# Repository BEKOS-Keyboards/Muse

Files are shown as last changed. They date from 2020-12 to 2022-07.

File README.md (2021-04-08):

# Muse
BOSS Keyboards Muse CAD and Design files

This is a full size "104" key keyboard that will run the QMK firmware, it has extra keys above the number row to allow for media control or other macros to be bound to the keys

Shield: [][cc-by-sa]

This work is licensed under a
[Creative Commons Attribution-ShareAlike 4.0 International License][cc-by-sa].

[][cc-by-sa]

[cc-by-sa]: http://creativecommons.org/licenses/by-sa/4.0/
[cc-by-sa-image]: https://licensebuttons.net/l/by-sa/4.0/88x31.png
[cc-by-sa-shield]: https://img.shields.io/badge/License-CC%20BY--SA%204.0-lightgrey.svg

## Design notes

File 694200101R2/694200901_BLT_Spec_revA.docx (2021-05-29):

Version | Changes | Date
A | Initial Release | 2021-05-25

Purpose

The purpose of this document is to describe the board level test requirements fort 694200901.

Related Documents

None

Specifications

1. The voltage at xxx shall be +5.0V +/- 0.4V
2. The voltage at xxx shall be +3.3V +/- 0.2V

694200901 Board Level Test Specification

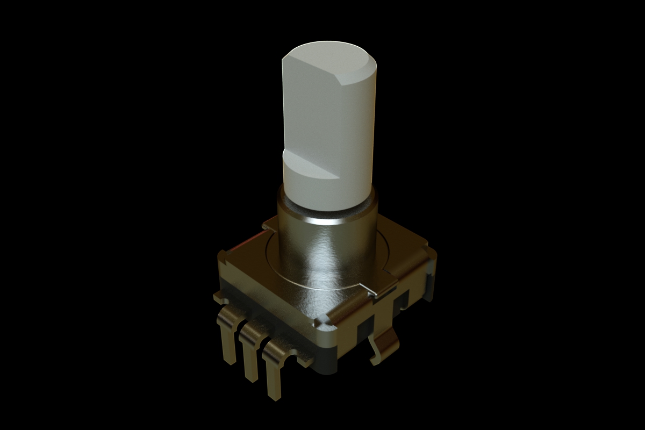
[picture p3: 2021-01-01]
3rd-party-footprints/pec11l-4xxxf-sxxxx-1.snapshot.2/Renderings/Trinityscsp__820.jpg

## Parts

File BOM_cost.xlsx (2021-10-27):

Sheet: Sheet1
part | mcmaster pn | quantity | price per | cost |  | in hand
316 Stainless Steel Pan Head Phillips Screws M2 x 0.40 mm Thread, 6mm Long | 90116A015 | 12 | 0.1023 | 1.2276 | 180 | 200
Tapered Heat-Set Inserts for Plastic Brass, M2 x 0.40 mm Thread Size, 2.900 mm Installed Length | 94180A307 | 12 | 0.1572 | 1.8864 | 180 | 200
316 Stainless Steel Pan Head Phillips Screws M3 x 0.50 mm Thread, 18mm Long | 90116A163 | 17 | 0.1151 | 1.9567 | 255 | 300
Tapered Heat-Set Inserts for Plastic Brass, M3 x 0.50 mm Thread Size, 3.800 mm Installed Length | 94180A331 | 21 | 0.1428 | 2.9988 | 315 | 400
316 Stainless Steel Pan Head Phillips Screws M3 x 0.50 mm Thread, 8mm Long | 90116A153 | 2 | 0.0695 | 0.139 | 30 | 100
316 Stainless Steel Pan Head Phillips Screws M3 x 0.50 mm Thread, 10mm Long | 90116A155 | 2 | 0.0752 | 0.1504 | 30 | 100
316 Stainless Steel Pan Head Phillips Screws M3 x 0.50 mm Thread, 14mm Long | 90116A160 | 2 | 0.1147 | 0.2294 | 30 | 100
Multipurpose Neoprene Strip with Certificate Adhesive-Back, with Certificate, 1/32" Thick, 50A Durometer, 2" x 36" | 1376N22 | 6 | 0.1048611111 | 0.6291666667 | 90 | 144
Multipurpose Neoprene Rubber Sheet 36" Wide, 1/32" Thick, 40A Durometer | 9455K91 | 1 | 3.117777778 |  | 15 | 18
Plate, Machined | xxxxx | 1 | 36.84 | 36.84 | 15 | 15
PCB |  | 1 | 29.42 | 29.42 | 15
pcb bom and assembly |  | 1 | 143.472 | 143.472 | 15
KNOB KNURLED 0.236" METAL | 226-4185-ND | 1 | 7.402666667 | 7.402666667 | 15
 |  |  |  |  |  |  | 144 | 19.2

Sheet: Sheet2
part | mcmaster pn | quantity | price per | cost |  | in hand
316 Stainless Steel Pan Head Phillips Screws M2 x 0.40 mm Thread, 6mm Long | 90116A015 | 12 | 0.1023 | 1.2276 | 180 | 200
Tapered Heat-Set Inserts for Plastic Brass, M2 x 0.40 mm Thread Size, 2.900 mm Installed Length | 94180A307 | 12 | 0.1572 | 1.8864 | 180 | 200
316 Stainless Steel Pan Head Phillips Screws M3 x 0.50 mm Thread, 18mm Long | 90116A163 | 17 | 0.1151 | 1.9567 | 255 | 300
Tapered Heat-Set Inserts for Plastic Brass, M3 x 0.50 mm Thread Size, 3.800 mm Installed Length | 94180A331 | 21 | 0.1428 | 2.9988 | 315 | 400
316 Stainless Steel Pan Head Phillips Screws M3 x 0.50 mm Thread, 8mm Long | 90116A153 | 2 | 0.0695 | 0.139 | 30 | 100
316 Stainless Steel Pan Head Phillips Screws M3 x 0.50 mm Thread, 10mm Long | 90116A155 | 2 | 0.0752 | 0.1504 | 30 | 100
316 Stainless Steel Pan Head Phillips Screws M3 x 0.50 mm Thread, 14mm Long | 90116A160 | 2 | 0.1147 | 0.2294 | 30 | 100
Multipurpose Neoprene Strip with Certificate Adhesive-Back, with Certificate, 1/32" Thick, 50A Durometer, 2" x 36" | 1376N22 | 8 | 0.1048611111 | 0.8388888889 | 120 | 144
Multipurpose Neoprene Rubber Sheet 36" Wide, 1/32" Thick, 40A Durometer | 9455K91 | 1 | 3.117777778 | 3.117777778 | 15 | 18
Plate, Machined | xxxxx | 1 | 36.84 | 36.84 | 15 | 15
PCB |  | 1 | 29.42 | 29.42 | 15
pcb bom and assembly |  | 1 | 143.472 | 143.472 | 15
duty |  | 1 | 21.3 | 21.3 | 15
KNOB KNURLED 0.236" METAL | 226-4185-ND | 1 | 7.402666667 | 7.402666667 | 15 |  |  |  |  | shipping required:
 |  | common base |  | 250.9796333 |  |  | user |  |  | Justin
extreme jet black PLA |  | 1 | 15.71285714 | 15.71285714 |  |  | Alyssa |  |  | Hume
Perect Yellow PLA |  | 1 | 14.995 | 14.995 |  |  | Hume |  |  | Griffin
Pine Green v2 PLA |  | 1 | 14.995 | 14.995 |  |  | Gerry |  |  | Megan?
Perfect Blue PLA |  | 1 | 14.995 | 14.995 |  |  | Doni |  |  | Patrick
Smoke Blue carbon Fiber |  | 1 | 26.995 | 26.995 |  |  | Doni
Perfect Orange Opaque PETG |  | 1 | 16.495 | 16.495 |  |  | Justin
Dark Blue CARBON FIBER Extreme PETG |  | 1 | 26.995 | 26.995 |  |  | Larkin
Marble v2 PETG PRO |  | 1 | 16.495 | 16.495 |  |  | Larkin
 |  |  |  |  |  |  |  | total cost ~ | 266

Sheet: Sheet3
who bought what
Doni: |  |  | John:
pcb |  |  | hardware
assembly |  |  | my filament
plate |  |  | rubber
most of the plastic |  |  | Knobs
pcb rnd1 | 2593.38
pcb rnd 2 | 441.3
plate | 552.6
duty | 319.61
total | 3906.89 | 1953.445
hardware,bags,rubber | 352.34
knobs | 111.04
packaging material
total | 463.38 | 231.69
 | larkin owes doni | 1721.755

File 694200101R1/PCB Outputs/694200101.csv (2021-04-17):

Id | Designator | Package | Quantity | Designation | Supplier and ref
1 | C27,C26,C15,C24,C22,C20,C13,C11 | CAPC1608X90N | 8 | CL10B474KA8NFNC
2 | U2 | SOT50P160X60-6N | 1 | USBLC6-2P6
3 | G1 | BossLogo | 1 | LOGO
4 | ENC1 | PEC11L4115FS0020 | 1 | PEC11L-4115F-S0020
5 | R22,R21 | RESC1508X55N | 2 | MCT06030Z0000ZP500
6 | C25 | C_0805_2012Metric | 1 | CL21A475KAQNNNE
7 | U6,U5 | QFN-48_EP_6.6x6.6_Pitch0.4mm | 2 | IS31FL3733B-QFLS4-TR
8 | D108,D107,D106,D105,D104,D103,D102,D101,D100,D99,D98,D97,D96,D95,D94,D93,D92,D91,D90,D89,D88,D87,D86,D85,D84,D83,D82,D81,D80,D79,D78,D77,D76,D75,D74,D73,D72,D71,D70,D69,D68,D67,D66,D65,D64,D63,D62,D61,D60,D59,D58,D57,D56,D55,D54,D53,D52,D51,D50,D49,D48,D47,D46,D45,D44,D43,D42,D41,D40,D39,D38,D37,D36,D35,D34,D33,D32,D31,D30,D29,D28,D27,D26,D25,D24,D23,D22,D21,D20,D19,D18,D17,D16,D15,D14,D13,D12,D11,D10,D9,D8,D7,D6,D5,D4,D3,D2,D1 | D_MiniMELF | 108 | LL4148
9 | D124,D220,D219,D218,D217,D216,D215,D214,D213,D212,D211,D210,D209,D208,D207,D206,D205,D204,D203,D202,D201,D200,D199,D198,D197,D196,D195,D194,D193,D192,D191,D190,D189,D188,D187,D186,D185,D184,D183,D182,D181,D180,D179,D178,D177,D176,D175,D174,D173,D172,D171,D170,D169,D168,D167,D166,D165,D164,D163,D162,D161,D160,D159,D158,D157,D156,D155,D154,D153,D152,D151,D150,D149,D148,D147,D146,D145,D144,D143,D142,D141,D140,D139,D138,D137,D136,D135,D134,D133,D132,D131,D130,D129,D128,D127,D126,D125,D123,D122,D121,D120,D119,D118,D117,D116,D115,D114,D113,D112,D111,D110,D109 | 4T | 112 | 19-337C_RSBHGHC-A88_4T
10 | SW77,SW95,SW85,SW82,SW92,SW9,SW44,SW43,SW42,SW41,SW40,SW107,SW106,SW105,SW104,SW103,SW102,SW101,SW100,SW99,SW98,SW97,SW96,SW94,SW93,SW91,SW90,SW89,SW88,SW87,SW86,SW84,SW83,SW81,SW80,SW79,SW78,SW76,SW75,SW74,SW73,SW72,SW71,SW70,SW69,SW68,SW67,SW66,SW65,SW64,SW63,SW62,SW61,SW60,SW59,SW58,SW57,SW56,SW55,SW54,SW53,SW52,SW51,SW50,SW49,SW48,SW47,SW46,SW45,SW39,SW38,SW37,SW36,SW35,SW34,SW33,SW32,SW31,SW30,SW29,SW28,SW27,SW26,SW25,SW24,SW23,SW22,SW21,SW20,SW19,SW18,SW17,SW16,SW15,SW14,SW13,SW12,SW11,SW10,SW8,SW7,SW6,SW5,SW4,SW3,SW2,SW1 | millmax-mxalps | 107 | MX_SW
11 | F1 | Fuse_1210_3225Metric | 1 | 1210L150THWR
12 | J2 | PinHeader_1x05_P2.54mm_Vertical | 1 | Conn_01x05_Male
13 | U3 | LQFP-64_10x10mm_P0.5mm | 1 | STM32L433RBTx
14 | SP2 | Mx_Stab_625 | 1 | MX_Stab_625
15 | H3 | MountingHole_3.5mm_Pad_TopBottom | 1 | PCB Common Earth
16 | H2,H1 | MountingHole_M2_edge | 2 | Mounting Slot
17 | FB1 | Yageo-RC0603-0-0-IPC_C | 1 | BBUP00160808600Y00
18 | CR1 | SMAJ9.0CA | 1 | SMAJ9.0CA
19 | C6,C3 | AVX-GRM124-0-0-IPC_C | 2 | 06035A100JAT2A
20 | C2 | Samsung-CL10-0-0-IPC_C | 1 | CL10B105KA8NNNC
21 | C10,C9,C5 | Samsung-0603_1608_Metric-0-0-0 | 3 | CL10B103KB8NNNC
22 | C1,C23,C21,C12,C19,C16,C14,C8,C7,C4 | Samsung-CL10-09_2006-0-IPC_C | 10 | CL10B104KB8NNNL
23 | R8,R7,R6,R5,R4,R3 | RESC2012X65N | 6 | RMCF0805FT510R
24 | SP8,SP7,SP6,SP3 | Mx_Stab_200 | 4 | MX_Stab_200
25 | SP5 | Mx_Stab_275 | 1 | MX_Stab_275
26 | SP4,SP1 | Mx_Stab_225 | 2 | MX_Stab_225
27 | Y1 | XTAL_ECS-480-10-33B-CKM-TR | 1 | ECS-480-10-33B-CKM-TR
28 | C18,C17 | CAPPC3528X210N | 2 | TAJB226K016RNJ
29 | R2,R1 | Yageo-RC0603-0-0-IPC_C | 2 | RC0603FR-075K1L
30 | R20,R17 | RESC6332X70N | 2 | RMCF2512FT20K0
31 | R19,R18,R16,R15 | RESC1508X55N | 4 | RMCF0603FT100K
32 | R10,R9 | RESC1508X55N | 2 | RMCF0603FT1K00
33 | R14,R13,R12,R11 | RESC1508X50N | 4 | RNCP0603FTD10K0
34 | U1 | AP2114HA-3.3TRG1 | 1 | AP2114HA-3.3TRG1
35 | J1 | Global_Connector_Technology-USB4085-GF-A-MFG | 1 | USB4085-GF-A
36 | U4 | STMicroelectronics-SO8N-SO-A-0-2-IPC_C | 1 | M24M02-DRMN6TP
37 | J3 | PinHeader_1x02_P2.54mm_Vertical | 1 | Conn_01x02_Male

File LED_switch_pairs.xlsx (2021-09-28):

U5
D109 | D113 | D117 | D121 | D125 | D129 | D133 | D137 | D141 | D145 | D149 | D153 | D157 | D161 | D165 | D169
1 | 9 | 14 | 20 | 25 | 35 | 40 | 45 | 50 | 56 | 62 | 66 | 71 | 75 | 79 | 84
D110 | D114 | D118 | D122 | D126 | D130 | D134 | D138 | D142 | D146 | D150 | D154 | D158 | D162 | D166 | D170
2 | 6 | 10 | 15 | 21 | 26 | 30 | 36 | 41 | 46 | 51 | 57 | 63 | 72 | 76 | 80
D111 | D115 | D119 | D123 | D127 | D131 | D135 | D139 | D143 | D147 | D151 | D155 | D159 | D163 | D167 | D171
3 | 11 | 16 | 22 | 27 | 31 | 37 | 42 | 47 | 52 | 58 | 64 | 67 | 73 | 77 | 81 | 64
D112 | D116 | D120 | D124 | D128 | D132 | D136 | D140 | D144 | D148 | D152 | D156 | D160 | D164 | D168 | D172
4 | 7 | 12 | 17 | 23 | 28 | 32 | 38 | 43 | 48 | 53 | 59 | 65 | 68 | 86 | 85
U6
D173 | D177 | D181 | D185 | D189 | D193 | D197 | D201 | D205 | D209 | D213 | D217
13 | 18 | 24 | 33 | 39 | 44 | 49 | 54 | 60 | 69 | 82 | ind1 |  |  |  |  | 48
D174 | D178 | D182 | D186 | D190 | D194 | D198 | D202 | D206 | D210 | D214 | D218 |  |  |  |  | 112
5 | 8 | 19 | 29 | 34 | 55 | 61 | 70 | 74 | 78 | 83 | 87
D175 | D179 | D183 | D187 | D191 | D195 | D199 | D203 | D207 | D211 | D215 | D219
91 | 97 | 102 | 100 | 96 | 101 | 90 | 95 | 89 | 88 | 94 | 99
D176 | D180 | D184 | D188 | D192 | D196 | D200 | D204 | D208 | D212 | D216 | D220
92 | 98 | 103 | 104 | 107 | 106 | 93 | 105 | ind5 | ind4 | ind3 | ind2

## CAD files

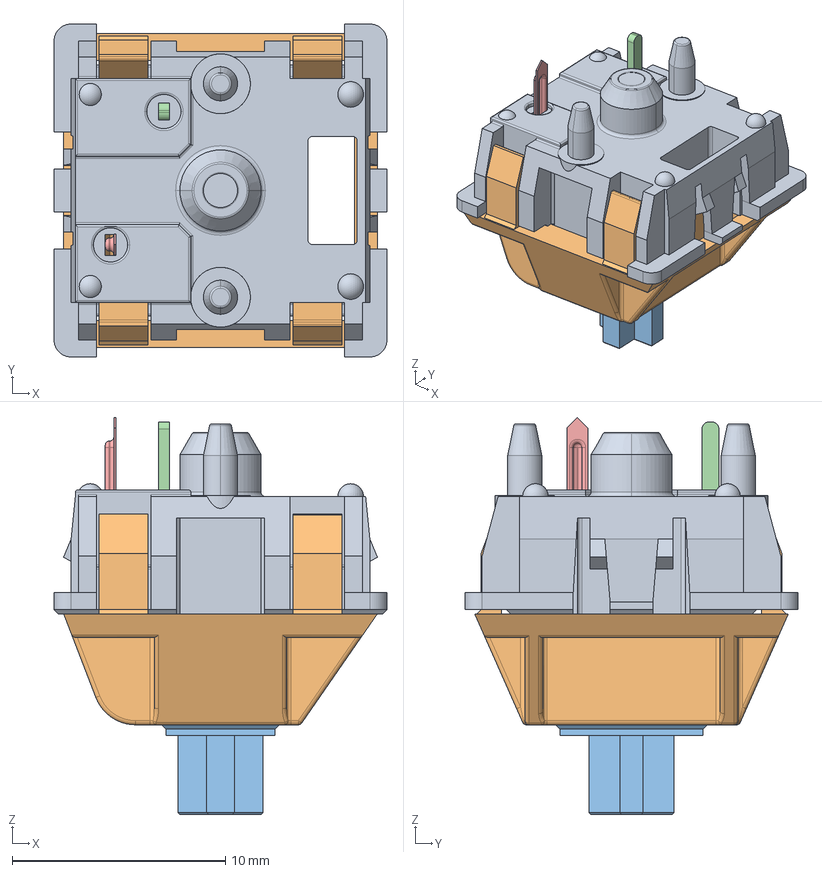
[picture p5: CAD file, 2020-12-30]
3rd-party-footprints/cherry-mx-1.snapshot.3/asm_mx_asm_PCB.stp
15.6 x 15.6 x 18.6 mm
MX_DOWN
MX_UP
UP_MX
MX_PIN
MX_SPRING
MX_CLICK

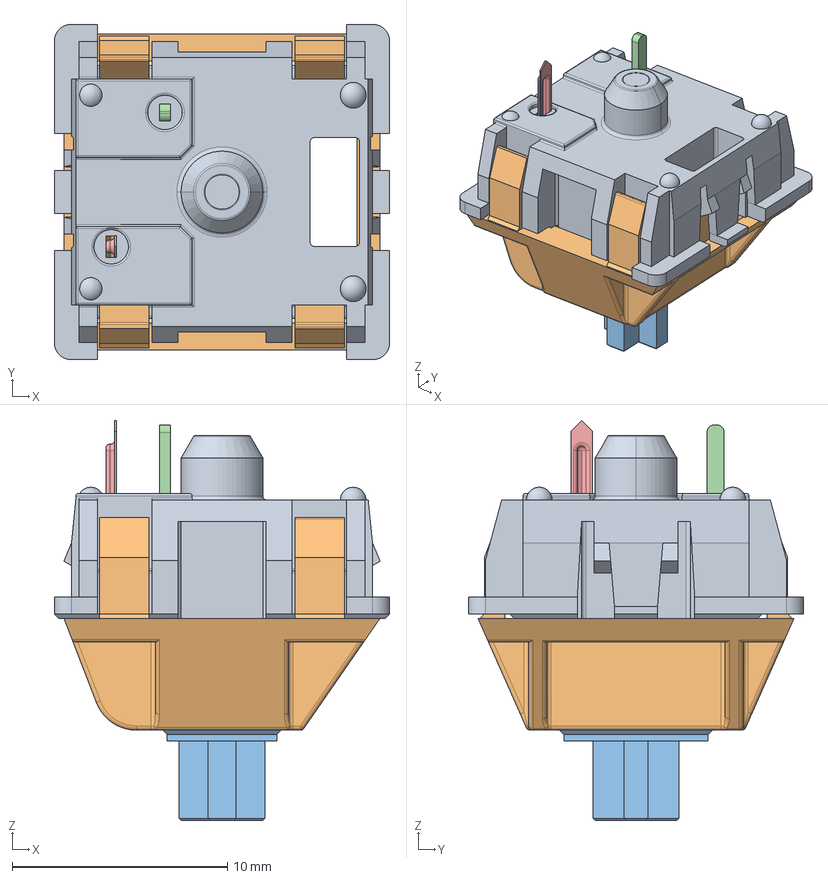
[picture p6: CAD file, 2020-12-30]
3rd-party-footprints/cherry-mx-1.snapshot.3/asm_mx_asm_PLATE.stp
15.6 x 15.6 x 18.6 mm
MX_DOWN
MX_UP
UP_MX
MX_PIN
MX_SPRING
MX_CLICK

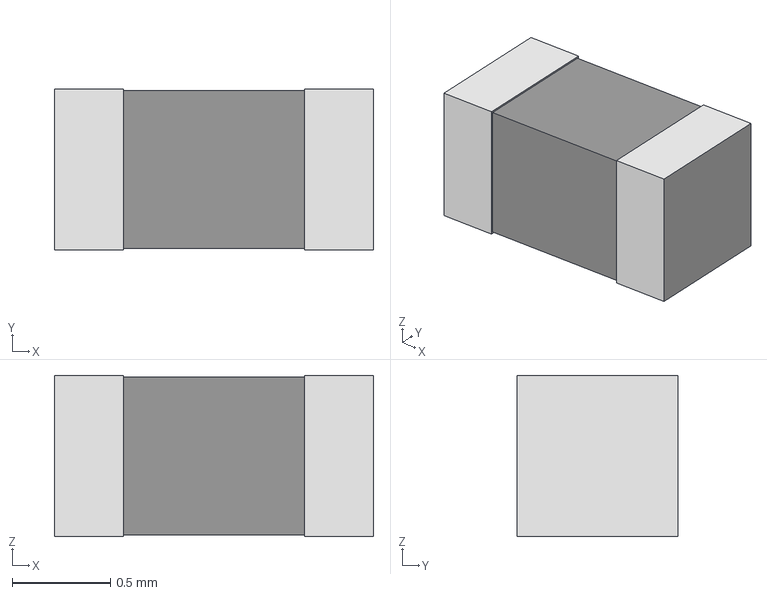
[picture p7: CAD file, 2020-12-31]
3rd-party-footprints/Cap_AVX_06035A100JAT2A/eec.models/AVX_-_06035A100JAT2A.step
1.62 x 0.82 x 0.82 mm

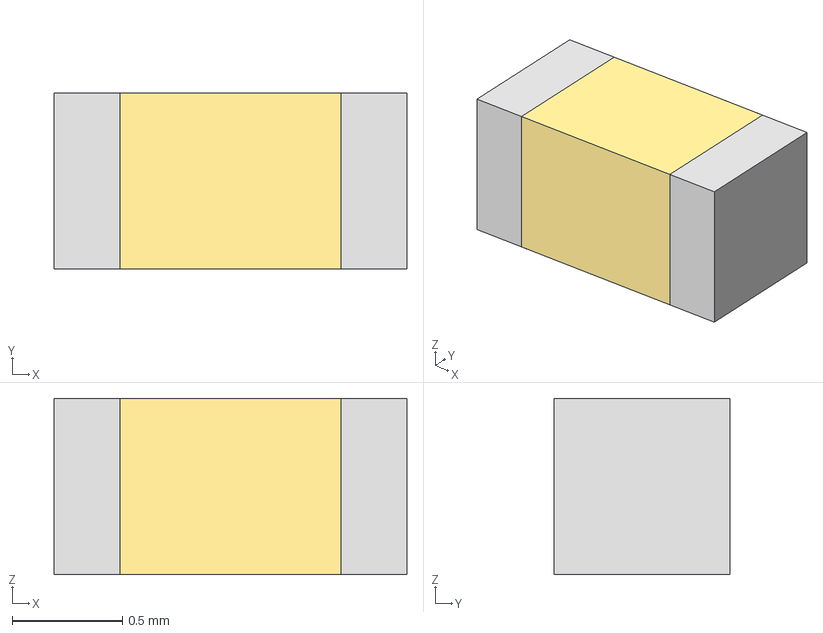
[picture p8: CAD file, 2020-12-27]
3rd-party-footprints/Cap_Samsung_CL10B103KB8NNNC/eec.models/Samsung_-_CL10B103KB8NNNC.step
1.60 x 0.8 x 0.8 mm

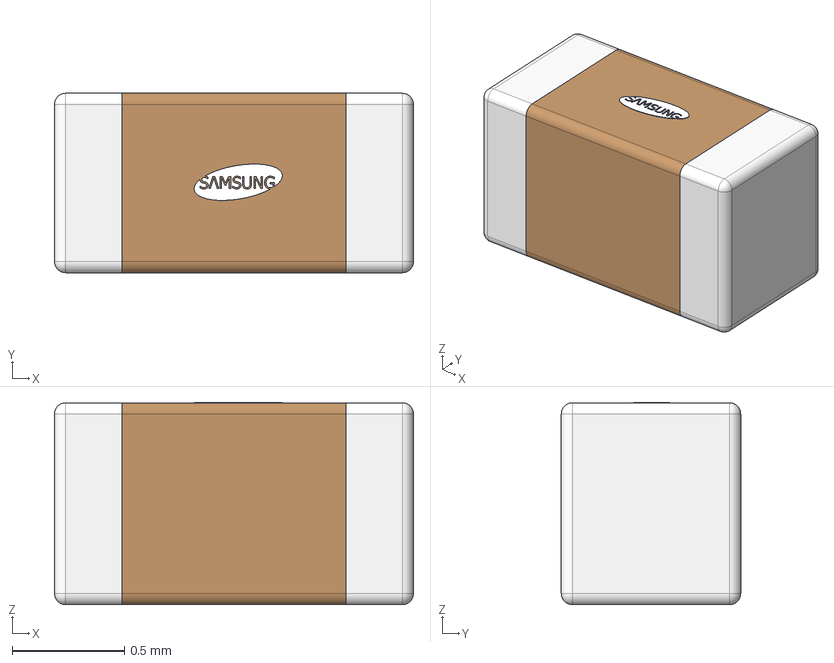
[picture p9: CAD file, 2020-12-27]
3rd-party-footprints/Cap_Samsung_CL10B104KB8NNNL/eec.models/Samsung_-_CL10B104KB8NNNL.step
1.60 x 0.8 x 0.902 mm
Samsung logo

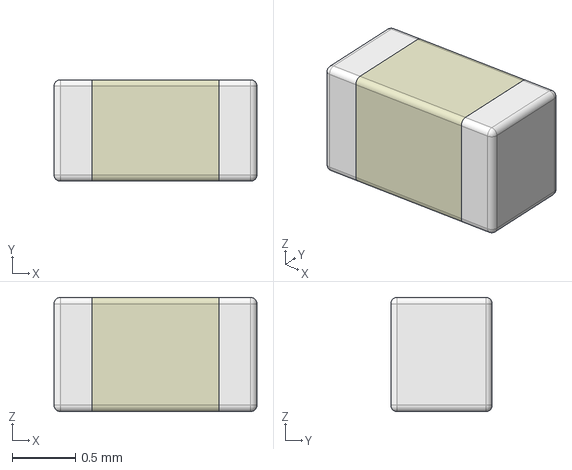
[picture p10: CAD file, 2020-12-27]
3rd-party-footprints/Cap_Samsung_CL10B105KA8NNNC/eec.models/Samsung_-_CL10B105KA8NNNC.step
1.60 x 0.8 x 0.9 mm

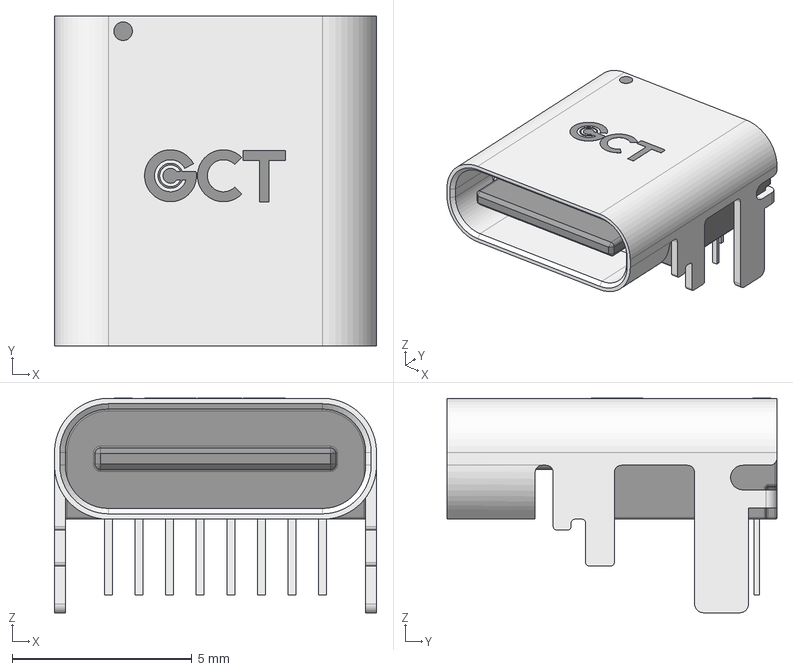
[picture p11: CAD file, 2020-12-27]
3rd-party-footprints/Conn_Global Connector Technology_USB4085-GF-A/eec.models/Global_Connector_Technology_-_USB4085-GF-A.step
8.95 x 9.17 x 5.96 mm
housing
plastic
pins
logo

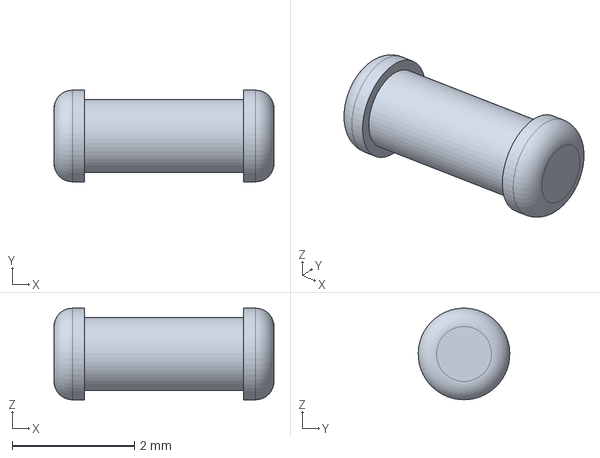
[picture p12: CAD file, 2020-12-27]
3rd-party-footprints/Diode_Fairchild_ON Semiconductor_LL4148/eec.models/Fairchild/ON_Semiconductor_-_LL4148.step
3.60 x 1.50 x 1.50 mm

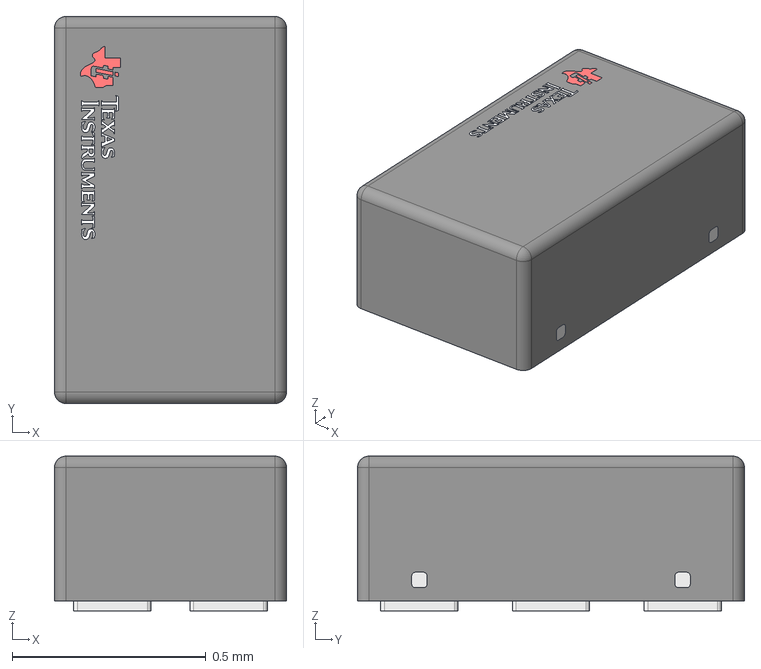
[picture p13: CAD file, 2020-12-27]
3rd-party-footprints/Diode_Texas Instruments_ESD122DMXR/eec.models/Texas_Instruments_-_ESD122DMXR.step
0.6 x 1.00 x 0.4 mm

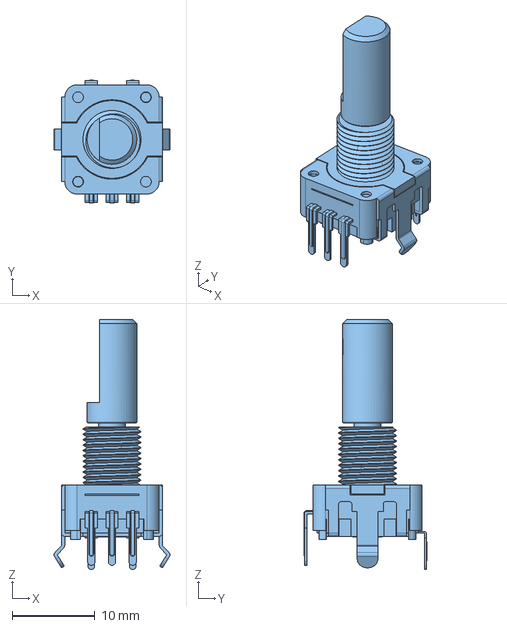
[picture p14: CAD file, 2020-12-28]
3rd-party-footprints/Enc_Bourns_PEC11R-4220F-S0024/eec.models/Bourns_-_PEC11R-4220F-S0024.step
14.0 x 14.9 x 30.2 mm

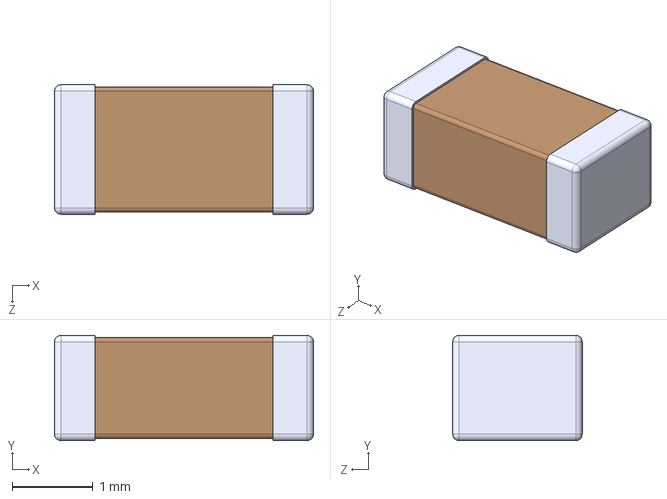
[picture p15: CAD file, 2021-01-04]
3rd-party-footprints/FBMJ3216HM600-T/FBMJ3216HM600-T.step
3.20 x 1.30 x 1.60 mm

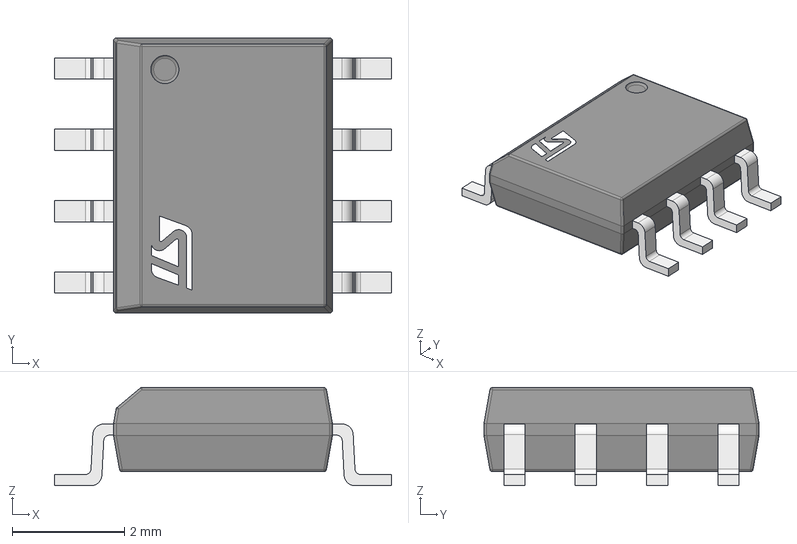
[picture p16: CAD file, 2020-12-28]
3rd-party-footprints/IC_STMicroelectronics_M24M02-DRMN6TP/eec.models/STMicroelectronics_-_M24M02-DRMN6TP.step
6.00 x 4.90 x 1.75 mm
pins
logo1

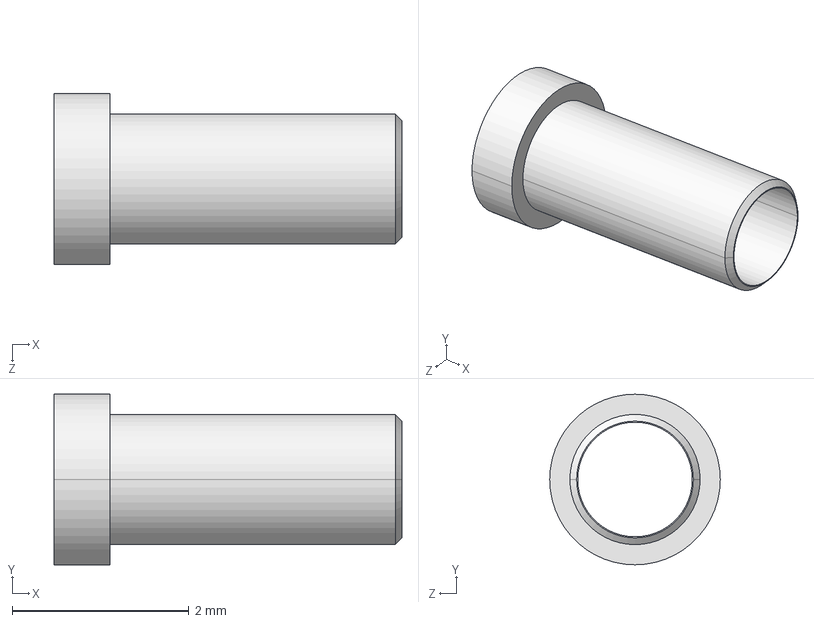
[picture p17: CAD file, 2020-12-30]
3rd-party-footprints/MillMax/mill-max-0305-2-15-80-47-XX-10-0.step
3.94 x 1.93 x 1.93 mm

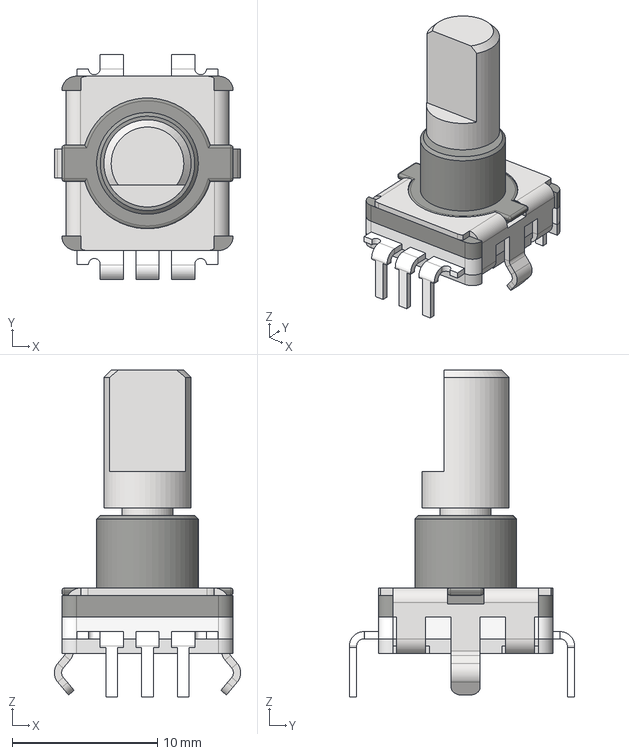
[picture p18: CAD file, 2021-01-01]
3rd-party-footprints/pec11l-4xxxf-sxxxx-1.snapshot.2/PEC11L-4xxxF-Sxxxx.stp
12.8 x 15.5 x 22.5 mm

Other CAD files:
3rd-party-footprints/CL10B474KA8NFNC/CL10B474KA8NFNC.step
3rd-party-footprints/RMCF0603FT100K/RMCF0603FT100K.step
3rd-party-footprints/RMCF0603FT1K00/RMCF0603FT1K00.step
3rd-party-footprints/RMCF0805FT510R/RMCF0805FT510R.step
3rd-party-footprints/19-337C_RSBHGHC-A88_4T.step
3rd-party-footprints/JS102011SAQN.STEP
3rd-party-footprints/RMCF2512FT20K0/RMCF2512FT20K0.step
3rd-party-footprints/RNCP0603FTD10K0/RNCP0603FTD10K0.step
3rd-party-footprints/TAJB226K016RNJ/TAJB226K016RNJ.step
3rd-party-footprints/USBLC6-2P6/USBLC6-2P6.step
3rd-party-footprints/smd-quartz-3-2x2-5mm-1.snapshot.5/KX7 SMD Quartz Crystal Resonator 3.2x2.5mm.step
3rd-party-footprints/ul_SMAJ90CA/KiCAD/2021-01-04_17-23-41/STEP/SMASeries_LTF.step
keyboard-layout/kb-plate-modded.dxf
keyboard-layout/kb-plate.dxf

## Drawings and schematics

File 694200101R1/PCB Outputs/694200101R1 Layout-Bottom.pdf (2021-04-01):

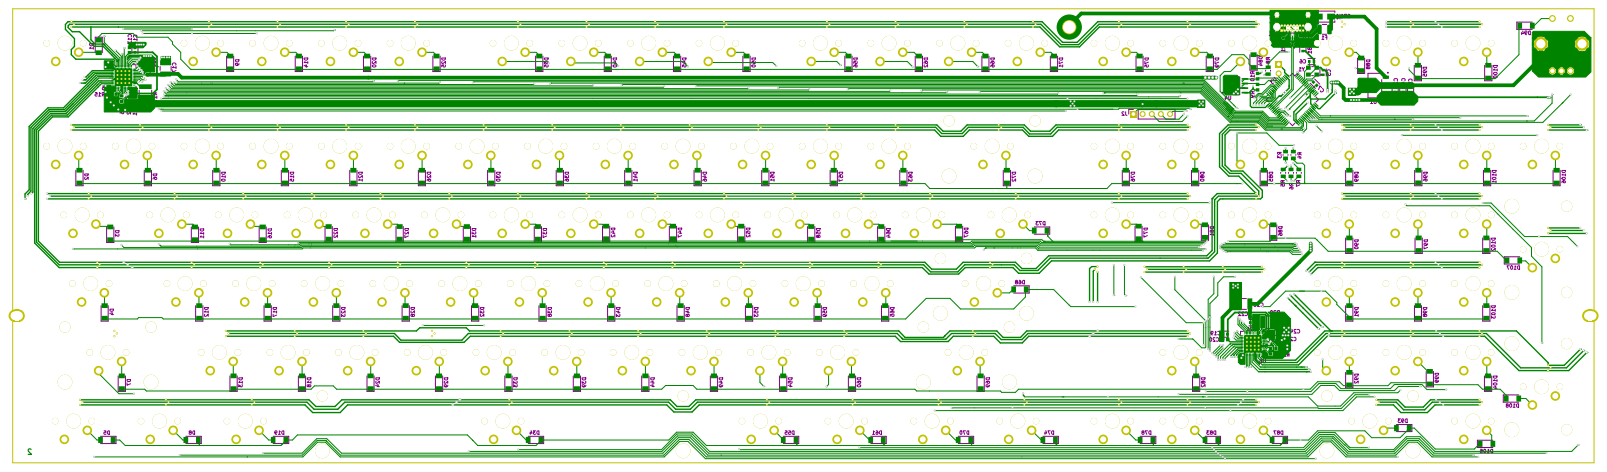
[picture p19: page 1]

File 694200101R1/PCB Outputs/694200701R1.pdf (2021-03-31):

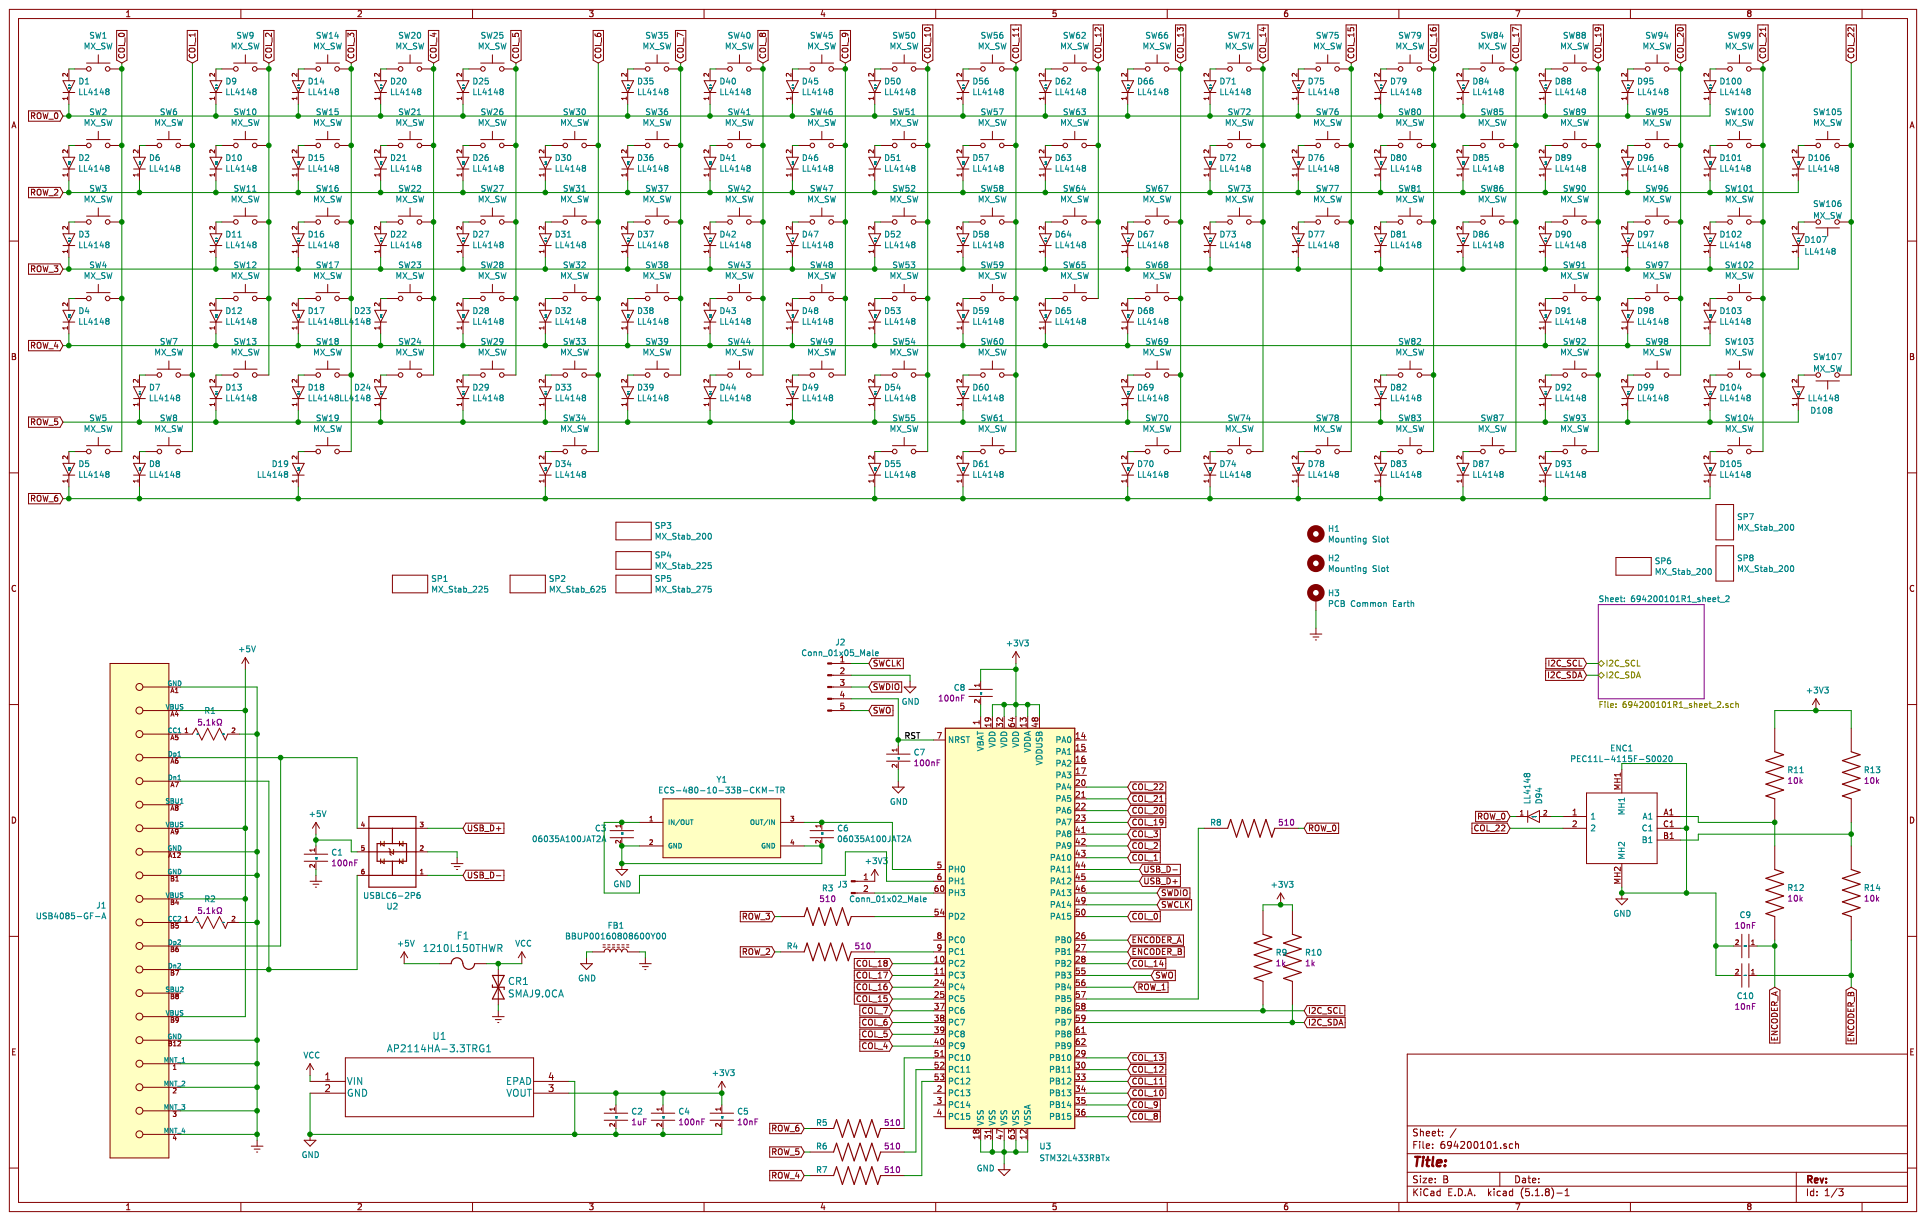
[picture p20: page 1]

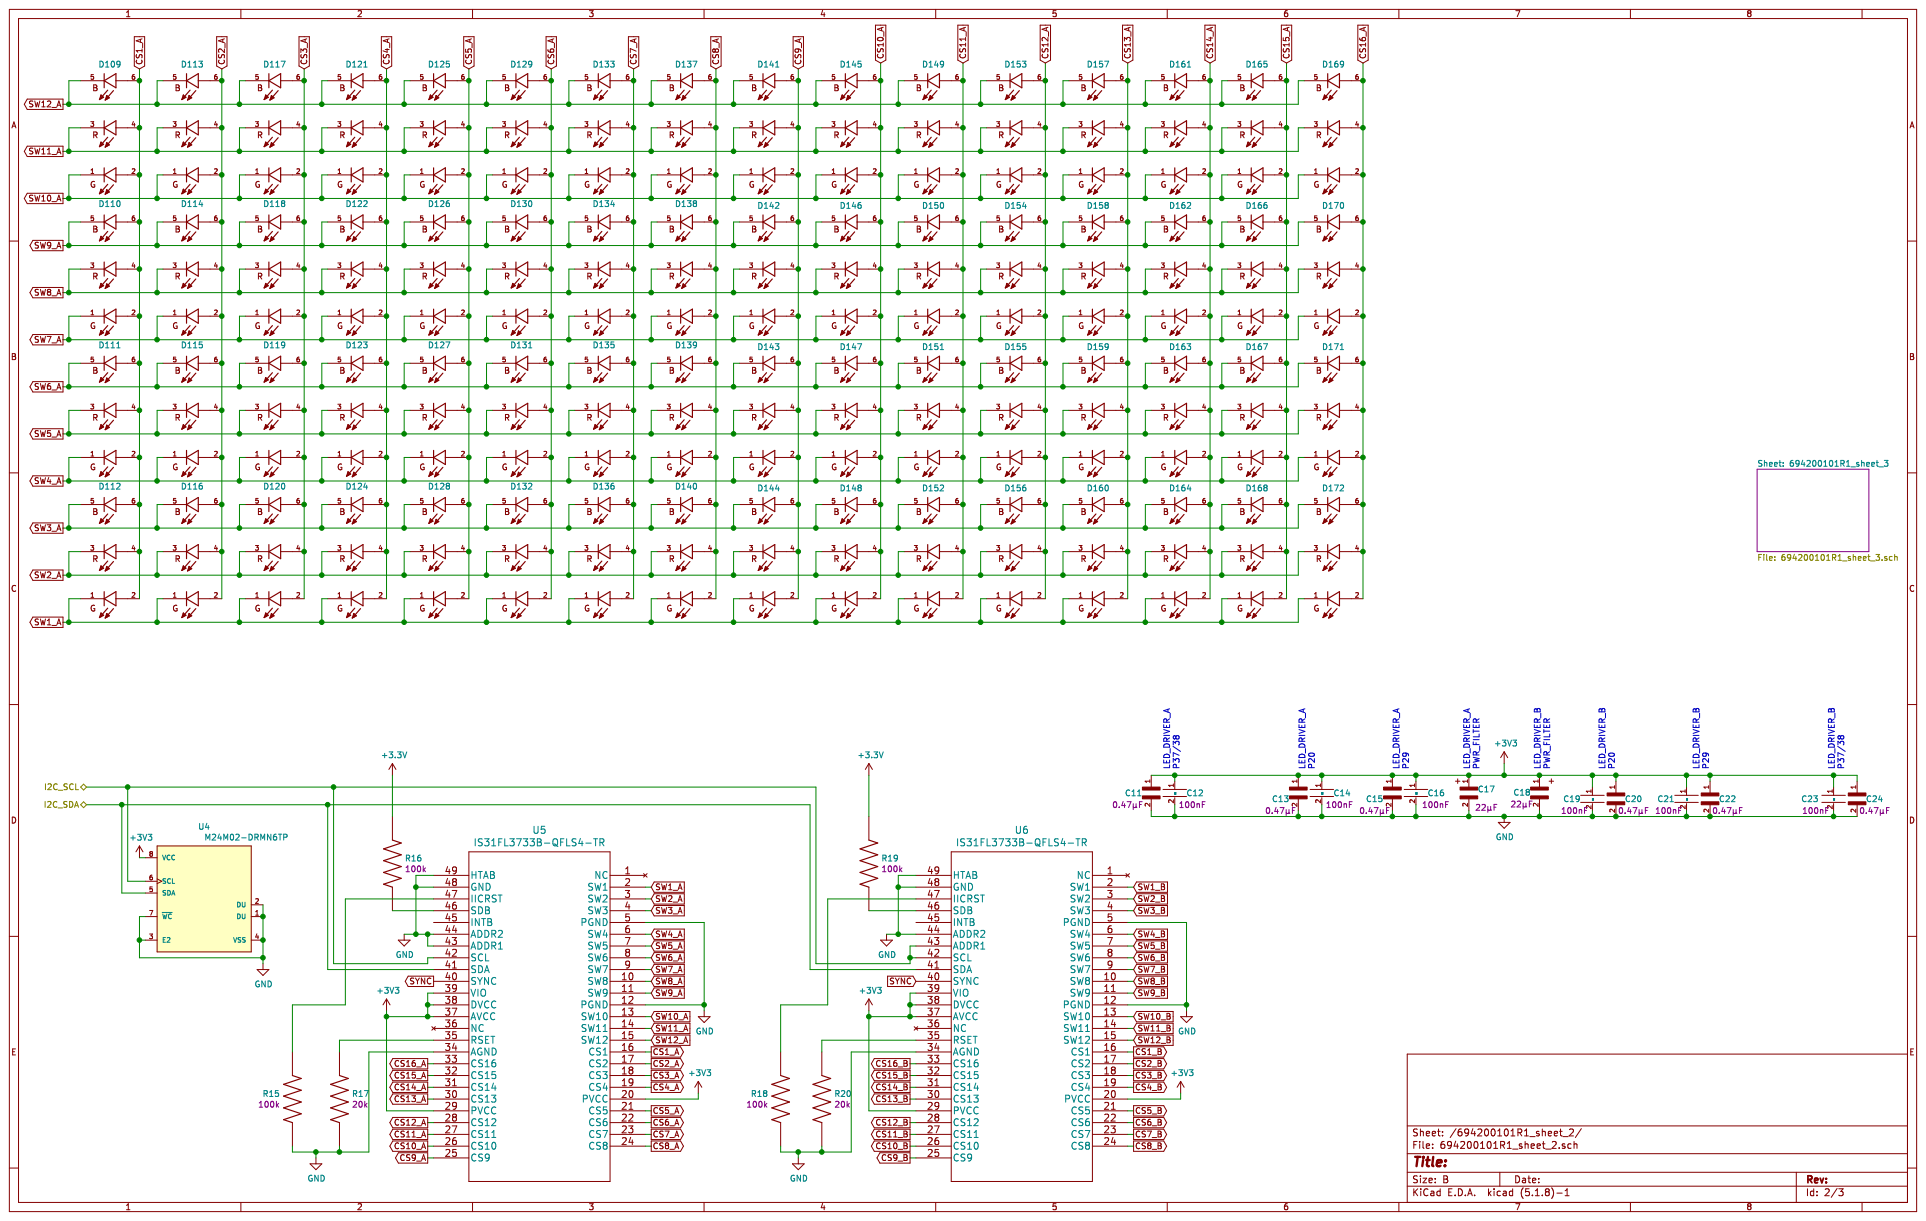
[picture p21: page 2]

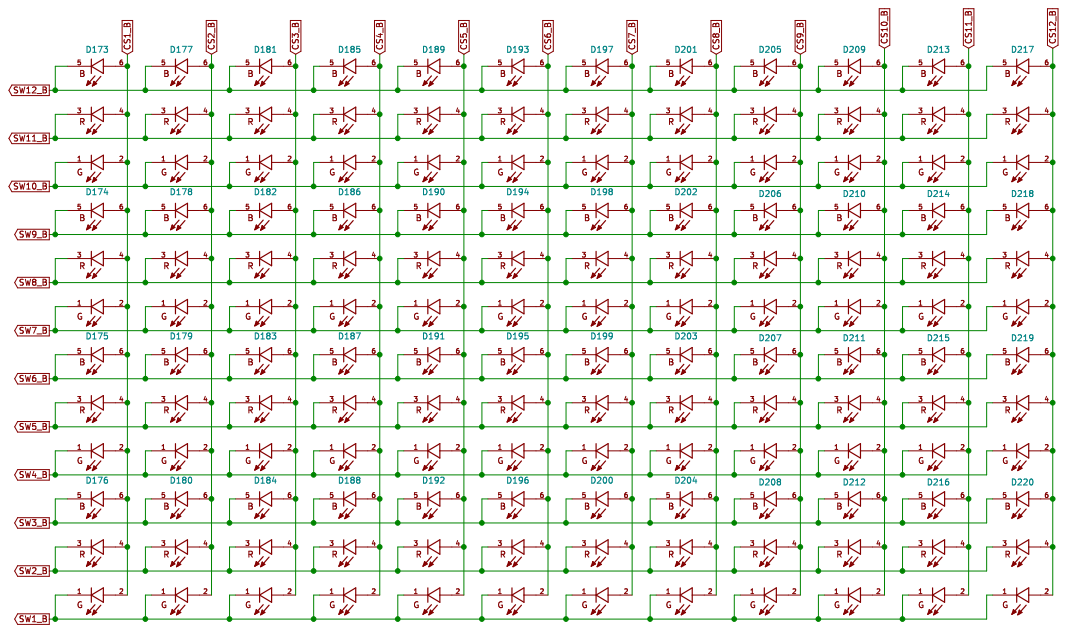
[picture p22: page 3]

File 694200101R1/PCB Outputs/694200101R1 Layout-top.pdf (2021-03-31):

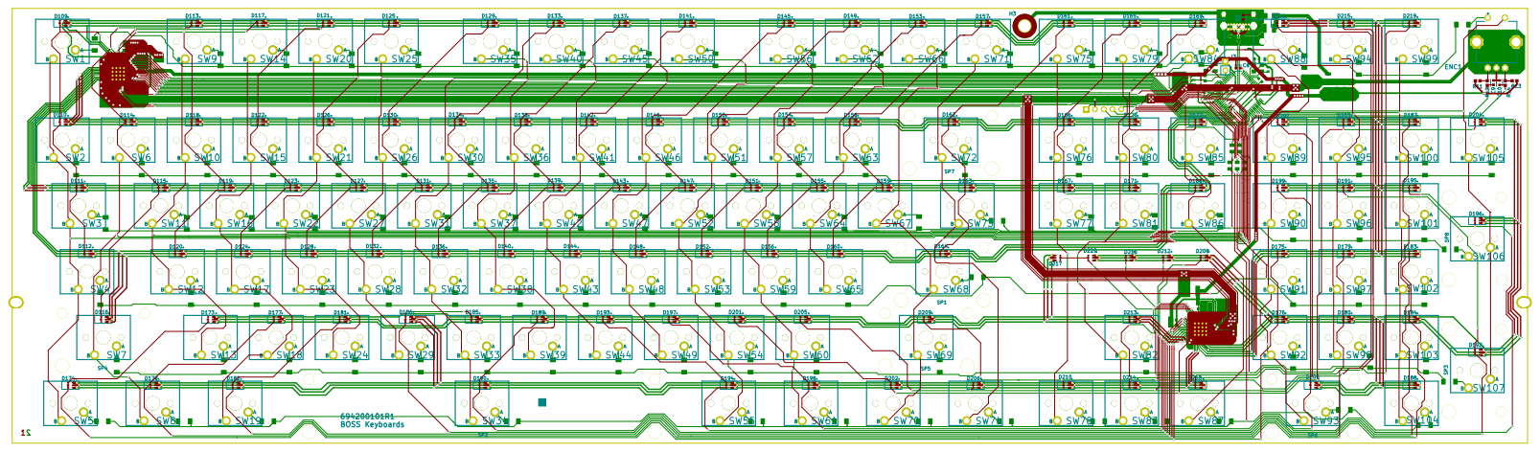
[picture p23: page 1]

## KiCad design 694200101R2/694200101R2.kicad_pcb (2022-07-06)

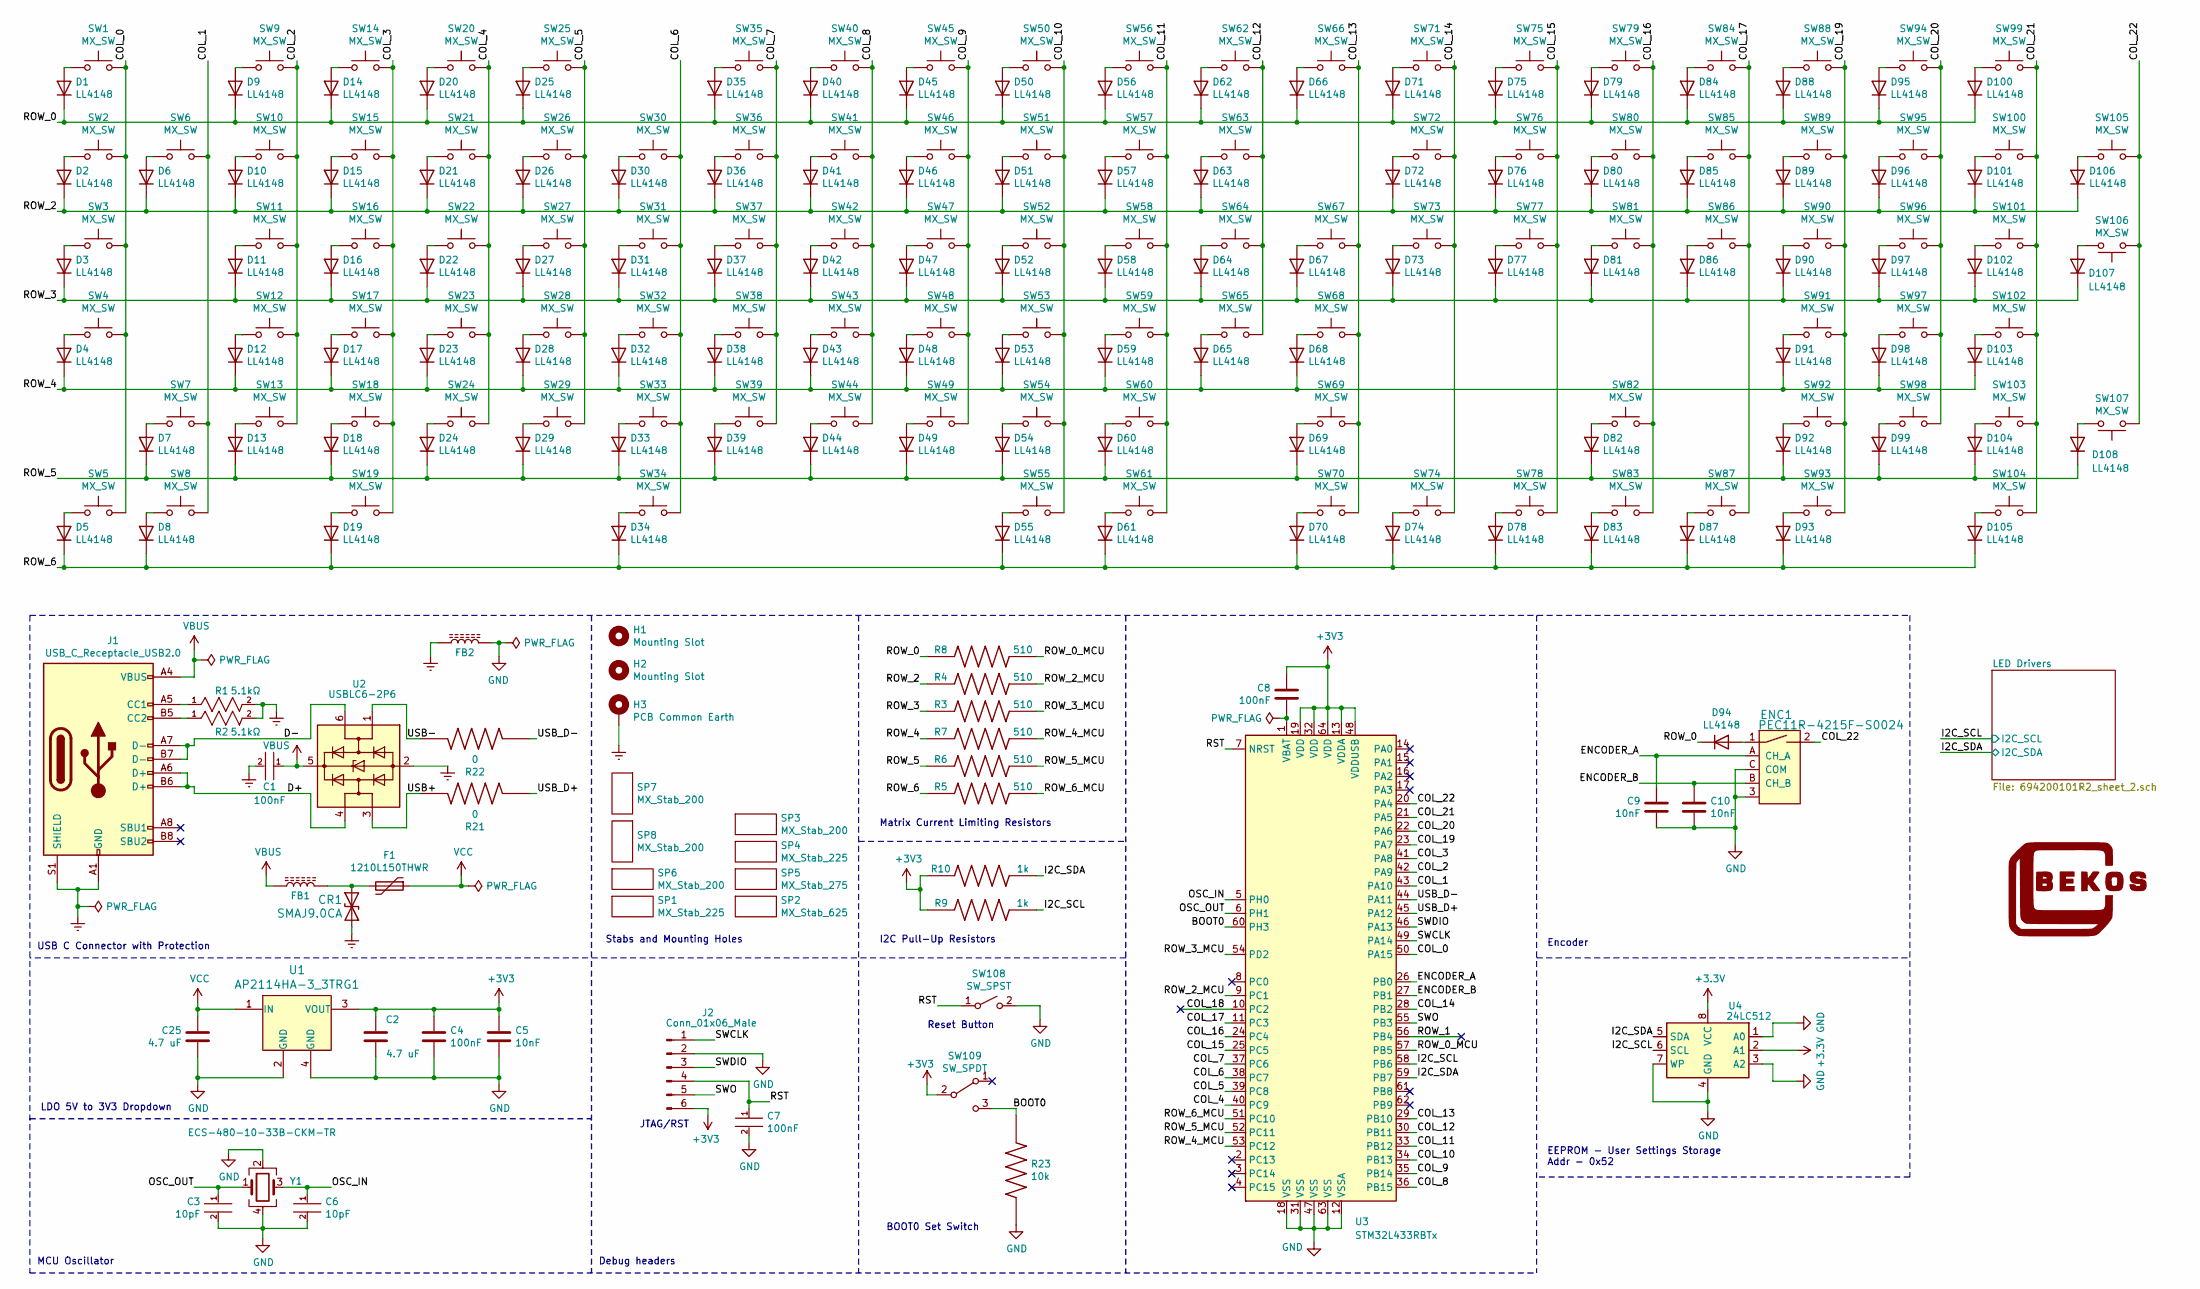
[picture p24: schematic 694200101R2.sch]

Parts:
C1, C7: CL10B104KB8NNNL; C_0603_1608Metric; tolerance 10%; voltage rating 50V
C2, C25: 4.7 uF; C_0805_2012Metric
C3, C6: 06035A100JAT2A; C_0603_1608Metric; tolerance 5%; voltage rating 50V; mouser part number 581-06035A100J; digikey description CAP CER 10PF 50V C0G/NP0 0603
C4, C8: 100nF; C_0603_1608Metric
C5, C9, C10: 10nF; C_0603_1608Metric
CR1: SMAJ9.0CA
D1, D9, D14, D20, D25, D35, D40, D45, D50, D56, D62, D66, D71, D75, D79: LL4148; D_MiniMELF
D2, D3, D4, D5, D6, D7, D8, D10, D11, D12, D13, D15, D16, D17, D18, D19, D21, D22, D23, D24, D26, D27, D28, D29, D30, D31, D32, D33, D34, D36, D37, D38, D39, D41, D42, D43, D44, D46, D47, D48, D49, D51, D52, D53, D54, D55, D57, D58, D59, D60, D61, D63, D64, D65, D67, D68, D69, D70, D72, D73, D74, D76, D77, D78, D80, D81, D82, D83, D84, D85, D86, D87, D88, D89, D90, D91, D92, D93, D94, D95, D96, D97, D98, D99, D100, D101, D102, D103, D104, D105, D106, D107, D108: LL4148; D_MiniMELF; mouser part number 512-LL4148; digikey description DIODE GEN PURP 100V 200MA SOD80
ENC1: PEC11R-4215F-S0024; Rotary_Encoder_Switched_PEC11R; MPN PEC11R-4215F-S0024; Digi-Key_PN PEC11R-4215F-S0024-ND
F1: 1210L150THWR; Fuse_1210_3225Metric_Castellated
FB1, FB2: FBMJ3216HM600-T; L_1206_3216Metric
H1, H2: Mounting Slot; MountingHole_M2_edge
H3: PCB Common Earth; MountingHole_3.5mm_Pad_TopBottom
J1: USB_C_Receptacle_USB2.0; USB_C_Receptacle_GCT_USB4085
J2: Conn_01x06_Male; PinHeader_1x06_P2.54mm_Vertical
R1, R2: RC0603FR-075K1L; R_0603_1608Metric; power rating 0.1W; tolerance 1%; mouser part number 603-RC0603FR-075K1L; digikey description RES SMD 5.1K OHM 1% 1/10W 0603
R3, R4, R5, R6, R7, R8: RMCF0805FT510R; R_0805_2012Metric
R9, R10: RMCF0603FT1K00; R_0603_1608Metric
R21, R22: MCT06030Z0000ZP500; R_0603_1608Metric
R23: RNCP0603FTD10K0; R_0603_1608Metric
SP1, SP4: MX_Stab_225; Mx_Stab_225
SP2: MX_Stab_625; Mx_Stab_625
SP3, SP6, SP7, SP8: MX_Stab_200; Mx_Stab_200
SP5: MX_Stab_275; Mx_Stab_275
SW1, SW2, SW3, SW4, SW5, SW6, SW7, SW8, SW9, SW10, SW11, SW12, SW13, SW14, SW15, SW16, SW17, SW18, SW19, SW20, SW21, SW22, SW23, SW24, SW25, SW26, SW27, SW28, SW29, SW30, SW31, SW32, SW33, SW34, SW35, SW36, SW37, SW38, SW39, SW40, SW41, SW42, SW43, SW44, SW45, SW46, SW47, SW48, SW49, SW50, SW51, SW52, SW53, SW54, SW55, SW56, SW57, SW58, SW59, SW60, SW61, SW62, SW63, SW64, SW65, SW66, SW67, SW68, SW69, SW70, SW71, SW72, SW73, SW74, SW75, SW76, SW77, SW78, SW79, SW80, SW81, SW82, SW83, SW84, SW85, SW86, SW87, SW88, SW89, SW90, SW91, SW92, SW93, SW94, SW95, SW96, SW97, SW98, SW99, SW100, SW101, SW102, SW103, SW104, SW105, SW106, SW107: MX_SW; millmax-mxalps
SW108: SW_SPST; SW_SPST_TL3342
SW109: SW_SPDT; SW_SPDT_PCM12
U1: AP2114HA-3_3TRG1; SOT-223; MPN AP2114H-3.3TRG1; Digi-Key_PN AP2114H-3.3TRG1DICT-ND
U2: USBLC6-2P6; SOT-666
U3: STM32L433RBTx; LQFP-64_10x10mm_P0.5mm
U4: 24LC512; SOIC-8_3.9x4.9mm_P1.27mm
Y1: ECS-480-10-33B-CKM-TR; XTAL_ECS-480-10-33B-CKM-TR

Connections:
/BOOT0: R23.1, SW109.3 (C), U3.60 (PH3)
/COL_0: SW1.2, SW2.2, SW3.2, SW4.2, SW5.2, U3.50 (PA15)
/COL_1: SW6.2, SW7.2, SW8.2, U3.43 (PA10)
/COL_2: SW9.2, SW10.2, SW11.2, SW12.2, SW13.2, U3.42 (PA9)
/COL_3: SW14.2, SW15.2, SW16.2, SW17.2, SW18.2, SW19.2, U3.41 (PA8)
/COL_4: SW20.2, SW21.2, SW22.2, SW23.2, SW24.2, U3.40 (PC9)
/COL_5: SW25.2, SW26.2, SW27.2, SW28.2, SW29.2, U3.39 (PC8)
/COL_6: SW30.2, SW31.2, SW32.2, SW33.2, SW34.2, U3.38 (PC7)
/COL_7: SW35.2, SW36.2, SW37.2, SW38.2, SW39.2, U3.37 (PC6)
/COL_8: SW40.2, SW41.2, SW42.2, SW43.2, SW44.2, U3.36 (PB15)
/COL_9: SW45.2, SW46.2, SW47.2, SW48.2, SW49.2, U3.35 (PB14)
/COL_10: SW50.2, SW51.2, SW52.2, SW53.2, SW54.2, SW55.2, U3.34 (PB13)
/COL_11: SW56.2, SW57.2, SW58.2, SW59.2, SW60.2, SW61.2, U3.33 (PB12)
/COL_12: SW62.2, SW63.2, SW64.2, SW65.2, U3.30 (PB11)
/COL_13: SW66.2, SW67.2, SW68.2, SW69.2, SW70.2, U3.29 (PB10)
/COL_14: SW71.2, SW72.2, SW73.2, SW74.2, U3.28 (PB2)
/COL_15: SW75.2, SW76.2, SW77.2, SW78.2, U3.25 (PC5)
/COL_16: SW79.2, SW80.2, SW81.2, SW82.2, SW83.2, U3.24 (PC4)
/COL_17: SW84.2, SW85.2, SW86.2, SW87.2, U3.11 (PC3)
/COL_18: U3.10 (PC2)
/COL_19: SW88.2, SW89.2, SW90.2, SW91.2, SW92.2, SW93.2, U3.23 (PA7)
/COL_20: SW94.2, SW95.2, SW96.2, SW97.2, SW98.2, U3.22 (PA6)
/COL_21: SW99.2, SW100.2, SW101.2, SW102.2, SW103.2, SW104.2, U3.21 (PA5)
/COL_22: ENC1.2, SW105.2, SW106.1, SW107.1, U3.20 (PA4)
/D+: J1.A6 (D+), J1.B6 (D+), U2.4 (I/O2)
/D-: J1.A7 (D-), J1.B7 (D-), U2.6 (I/O1)
/ENCODER_A: C9.1, ENC1.A (CH_A), U3.26 (PB0)
/ENCODER_B: C10.1, ENC1.B (CH_B), U3.27 (PB1)
/I2C_SCL: R9.2, U3.58 (PB6), U4.6 (SCL); also elsewhere on the board
/I2C_SDA: R10.2, U3.59 (PB7), U4.5 (SDA); also elsewhere on the board
/OSC_IN: C6.1, U3.5 (PH0), Y1.3
/OSC_OUT: C3.1, U3.6 (PH1), Y1.1
/ROW_0: D1.1 (K), D9.1 (K), D14.1 (K), D20.1 (K), D25.1 (K), D35.1 (K), D40.1 (K), D45.1 (K), D50.1 (K), D56.1 (K), D62.1 (K), D66.1 (K), D71.1 (K), D75.1 (K), D79.1 (K), D84.1 (K), D88.1 (K), D94.1 (K), D95.1 (K), D100.1 (K), R8.2
/ROW_0_MCU: R8.1, U3.57 (PB5)
/ROW_1: U3.56 (PB4)
/ROW_2: D2.1 (K), D6.1 (K), D10.1 (K), D15.1 (K), D21.1 (K), D26.1 (K), D30.1 (K), D36.1 (K), D41.1 (K), D46.1 (K), D51.1 (K), D57.1 (K), D63.1 (K), D72.1 (K), D76.1 (K), D80.1 (K), D85.1 (K), D89.1 (K), D96.1 (K), D101.1 (K), D106.1 (K), R4.1
/ROW_2_MCU: R4.2, U3.9 (PC1)
/ROW_3: D3.1 (K), D11.1 (K), D16.1 (K), D22.1 (K), D27.1 (K), D31.1 (K), D37.1 (K), D42.1 (K), D47.1 (K), D52.1 (K), D58.1 (K), D64.1 (K), D67.1 (K), D73.1 (K), D77.1 (K), D81.1 (K), D86.1 (K), D90.1 (K), D97.1 (K), D102.1 (K), D107.1 (K), R3.1
/ROW_3_MCU: R3.2, U3.54 (PD2)
/ROW_4: D4.1 (K), D12.1 (K), D17.1 (K), D23.1 (K), D28.1 (K), D32.1 (K), D38.1 (K), D43.1 (K), D48.1 (K), D53.1 (K), D59.1 (K), D65.1 (K), D68.1 (K), D91.1 (K), D98.1 (K), D103.1 (K), R7.1
/ROW_4_MCU: R7.2, U3.53 (PC12)
/ROW_5: D7.1 (K), D13.1 (K), D18.1 (K), D24.1 (K), D29.1 (K), D33.1 (K), D39.1 (K), D44.1 (K), D49.1 (K), D54.1 (K), D60.1 (K), D69.1 (K), D82.1 (K), D92.1 (K), D99.1 (K), D104.1 (K), D108.1 (K), R6.1
/ROW_5_MCU: R6.2, U3.52 (PC11)
/ROW_6: D5.1 (K), D8.1 (K), D19.1 (K), D34.1 (K), D55.1 (K), D61.1 (K), D70.1 (K), D74.1 (K), D78.1 (K), D83.1 (K), D87.1 (K), D93.1 (K), D105.1 (K), R5.1
/ROW_6_MCU: R5.2, U3.51 (PC10)
/RST: C7.1, J2.4, SW108.1 (A), U3.7 (NRST)
/SWCLK: J2.1, U3.49 (PA14)
/SWDIO: J2.3, U3.46 (PA13)
/SWO: J2.5, U3.55 (PB3)
/USB+: R21.1, U2.3 (I/O2)
/USB-: R22.1, U2.1 (I/O1)
/USB_D+: R21.2, U3.45 (PA12)
/USB_D-: R22.2, U3.44 (PA11)
Earth: C1.2, CR1.2 (A2), FB2.1, H3.1, J1.A1 (GND), J1.A12 (GND), J1.B1 (GND), J1.B12 (GND), J1.S1 (SHIELD), R1.2, R2.2, U2.2 (GND)
GND: C2.2, C3.2, C4.2, C5.2, C6.2, C7.2, C9.2, C10.2, C25.2, ENC1.3, ENC1.C (COM), FB2.2, J2.2, R23.2, SW108.2 (B), U1.2 (GND), U1.4 (GND), U3.12 (VSSA), U3.18 (VSS), U3.31 (VSS), U3.47 (VSS), U3.63 (VSS), U4.1 (A0), U4.3 (A2), U4.4 (GND), U4.7 (WP), Y1.2, Y1.4; also elsewhere on the board
unnamed: C8.2, U3.1 (VBAT)
unnamed: CR1.1 (A1), F1.2, FB1.1
unnamed: D1.2 (A), SW1.1
unnamed: D2.2 (A), SW2.1
unnamed: D3.2 (A), SW3.1
unnamed: D4.2 (A), SW4.1
unnamed: D5.2 (A), SW5.1
unnamed: D6.2 (A), SW6.1
unnamed: D7.2 (A), SW7.1
unnamed: D8.2 (A), SW8.1
unnamed: D9.2 (A), SW9.1
unnamed: D10.2 (A), SW10.1
unnamed: D11.2 (A), SW11.1
unnamed: D12.2 (A), SW12.1
unnamed: D13.2 (A), SW13.1
unnamed: D14.2 (A), SW14.1
unnamed: D15.2 (A), SW15.1
unnamed: D16.2 (A), SW16.1
unnamed: D17.2 (A), SW17.1
unnamed: D18.2 (A), SW18.1
unnamed: D19.2 (A), SW19.1
unnamed: D20.2 (A), SW20.1
unnamed: D21.2 (A), SW21.1
unnamed: D22.2 (A), SW22.1
unnamed: D23.2 (A), SW23.1
unnamed: D24.2 (A), SW24.1
unnamed: D25.2 (A), SW25.1
unnamed: D26.2 (A), SW26.1
unnamed: D27.2 (A), SW27.1
unnamed: D28.2 (A), SW28.1
unnamed: D29.2 (A), SW29.1
unnamed: D30.2 (A), SW30.1
unnamed: D31.2 (A), SW31.1
unnamed: D32.2 (A), SW32.1
unnamed: D33.2 (A), SW33.1
unnamed: D34.2 (A), SW34.1
unnamed: D35.2 (A), SW35.1
unnamed: D36.2 (A), SW36.1
unnamed: D37.2 (A), SW37.1
unnamed: D38.2 (A), SW38.1
unnamed: D39.2 (A), SW39.1
unnamed: D40.2 (A), SW40.1
unnamed: D41.2 (A), SW41.1
unnamed: D42.2 (A), SW42.1
unnamed: D43.2 (A), SW43.1
unnamed: D44.2 (A), SW44.1
unnamed: D45.2 (A), SW45.1
unnamed: D46.2 (A), SW46.1
unnamed: D47.2 (A), SW47.1
unnamed: D48.2 (A), SW48.1
unnamed: D49.2 (A), SW49.1
unnamed: D50.2 (A), SW50.1
unnamed: D51.2 (A), SW51.1
unnamed: D52.2 (A), SW52.1
unnamed: D53.2 (A), SW53.1
unnamed: D54.2 (A), SW54.1
unnamed: D55.2 (A), SW55.1
unnamed: D56.2 (A), SW56.1
unnamed: D57.2 (A), SW57.1
unnamed: D58.2 (A), SW58.1
unnamed: D59.2 (A), SW59.1
unnamed: D60.2 (A), SW60.1
unnamed: D61.2 (A), SW61.1
unnamed: D62.2 (A), SW62.1
unnamed: D63.2 (A), SW63.1
unnamed: D64.2 (A), SW64.1
unnamed: D65.2 (A), SW65.1
unnamed: D66.2 (A), SW66.1
unnamed: D67.2 (A), SW67.1
unnamed: D68.2 (A), SW68.1
unnamed: D69.2 (A), SW69.1
unnamed: D70.2 (A), SW70.1
unnamed: D71.2 (A), SW71.1
unnamed: D72.2 (A), SW72.1
unnamed: D73.2 (A), SW73.1
unnamed: D74.2 (A), SW74.1
unnamed: D75.2 (A), SW75.1
unnamed: D76.2 (A), SW76.1
unnamed: D77.2 (A), SW77.1
unnamed: D78.2 (A), SW78.1
unnamed: D79.2 (A), SW79.1
unnamed: D80.2 (A), SW80.1
unnamed: D81.2 (A), SW81.1
unnamed: D82.2 (A), SW82.1
unnamed: D83.2 (A), SW83.1
unnamed: D84.2 (A), SW84.1
unnamed: D85.2 (A), SW85.1
unnamed: D86.2 (A), SW86.1
unnamed: D87.2 (A), SW87.1
unnamed: D88.2 (A), SW88.1
unnamed: D89.2 (A), SW89.1
unnamed: D90.2 (A), SW90.1
unnamed: D91.2 (A), SW91.1
unnamed: D92.2 (A), SW92.1
unnamed: D93.2 (A), SW93.1
unnamed: D94.2 (A), ENC1.1
unnamed: D95.2 (A), SW94.1
unnamed: D96.2 (A), SW95.1
unnamed: D97.2 (A), SW96.1
unnamed: D98.2 (A), SW97.1
unnamed: D99.2 (A), SW98.1
unnamed: D100.2 (A), SW99.1
unnamed: D101.2 (A), SW100.1
unnamed: D102.2 (A), SW101.1
unnamed: D103.2 (A), SW102.1
unnamed: D104.2 (A), SW103.1
unnamed: D105.2 (A), SW104.1
unnamed: D106.2 (A), SW105.1
unnamed: D107.2 (A), SW106.2
unnamed: D108.2 (A), SW107.2
unnamed: J1.A5 (CC1), R1.1
unnamed: J1.B5 (CC2), R2.1
VBUS: C1.1, FB1.2, J1.A4 (VBUS), J1.A9 (VBUS), J1.B4 (VBUS), J1.B9 (VBUS), U2.5 (VBUS)
VCC: C25.1, F1.1, U1.1 (IN); also elsewhere on the board

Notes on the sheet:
USB C Connector with Protection
LDO 5V to 3V3 Dropdown
MCU Oscillator
JTAG/RST
Stabs and Mounting Holes
Matrix Current Limiting Resistors
I2C Pull-Up Resistors
Encoder
Debug headers
BOOT0 Set Switch
Reset Button
EEPROM - User Settings Storage Addr - 0x52

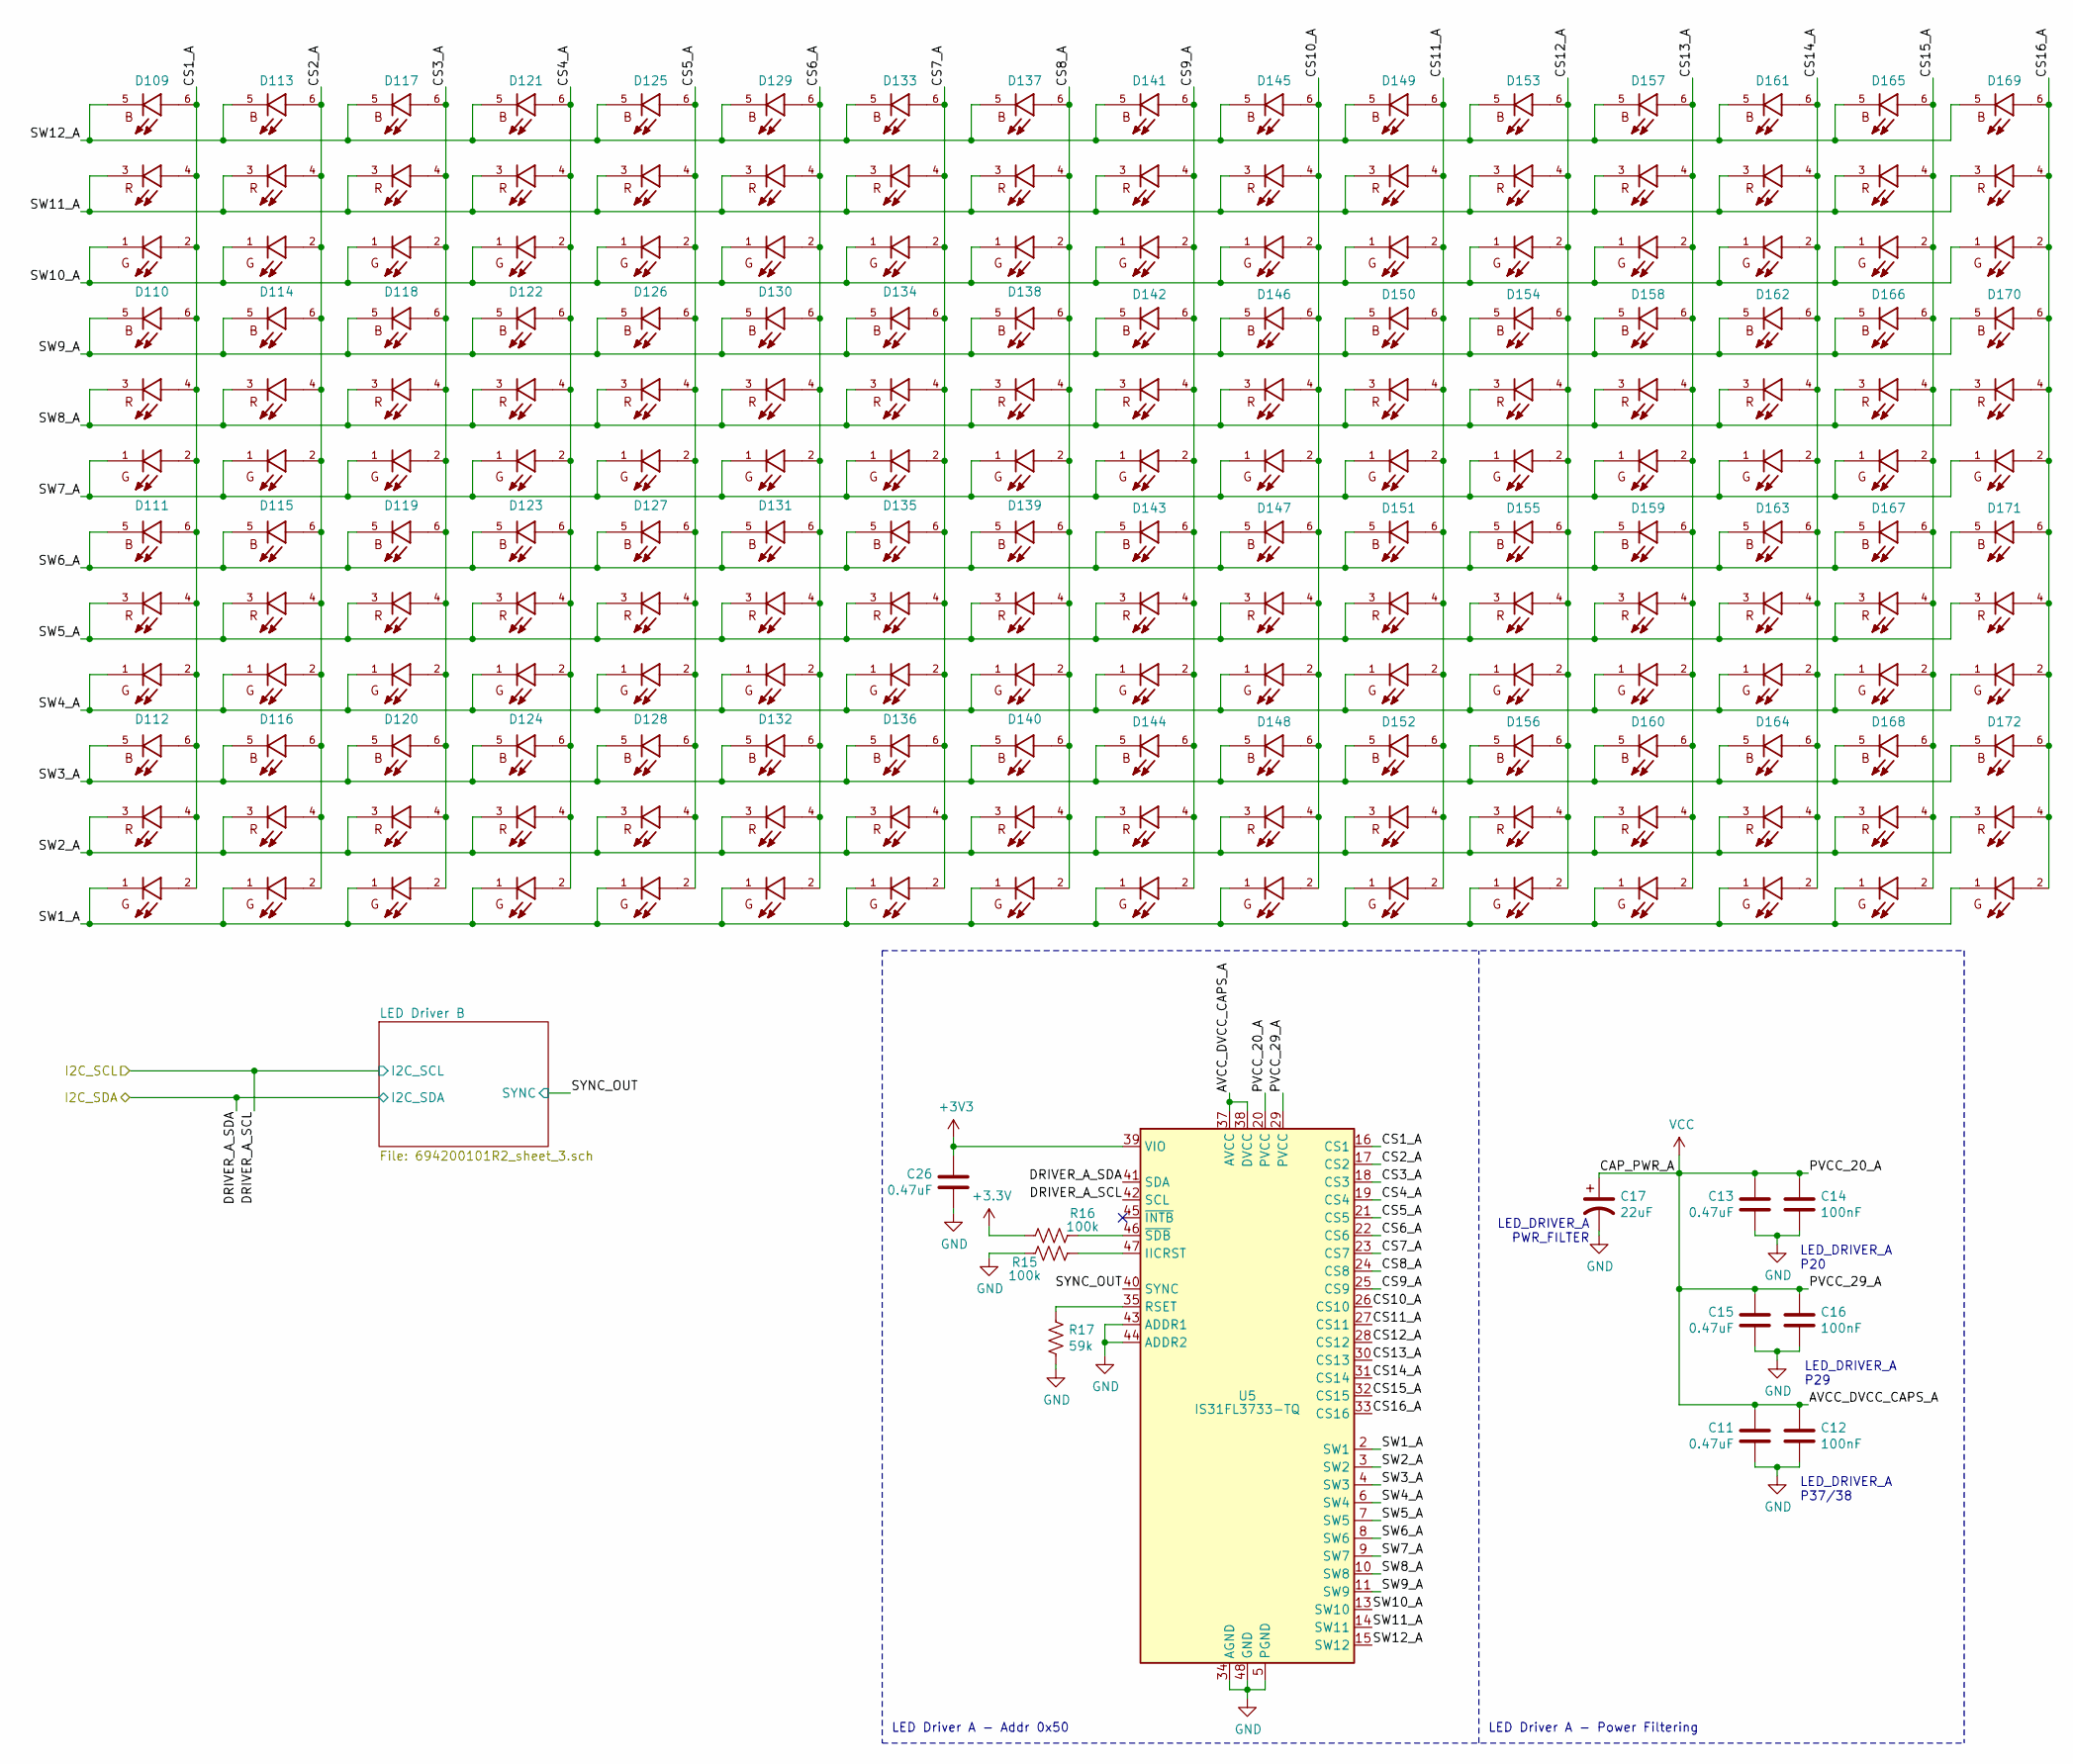
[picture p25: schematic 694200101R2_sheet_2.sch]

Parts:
C11, C13, C15, C26: 0.47uF; C_0603_1608Metric
C12, C14, C16: 100nF; C_0603_1608Metric
C17: 22uF; CP_EIA-3528-21_Kemet-B
D109, D110, D111, D112, D113, D114, D115, D116, D117, D118, D119, D120, D121, D122, D123, D124, D125, D126, D127, D128, D129, D130, D131, D132, D133, D134, D135, D136, D137, D138, D139, D140, D141, D142, D143, D144, D145, D146, D147, D148, D149, D150, D151, D152, D153, D154, D155, D156, D157, D158, D159, D160, D161, D162, D163, D164, D165, D166, D167, D168, D169, D170, D171, D172: 19-337C_RSBHGHC-A88_4T; 4T; PARTREV 2
R15, R16: 100k; R_0603_1608Metric
R17: 59k; R_2512_6332Metric
U5: IS31FL3733-TQ; TQFP-48-1EP_7x7mm_P0.5mm_EP5x5mm_ThermalVias

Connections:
/I2C_SCL: U5.42 (SCL); also elsewhere on the board
/I2C_SDA: U5.41 (SDA); also elsewhere on the board
/LED Drivers/CS1_A: D109.2, D109.4, D109.6, D110.2, D110.4, D110.6, D111.2, D111.4, D111.6, D112.2, D112.4, D112.6, U5.16 (CS1)
/LED Drivers/CS2_A: D113.2, D113.4, D113.6, D114.2, D114.4, D114.6, D115.2, D115.4, D115.6, D116.2, D116.4, D116.6, U5.17 (CS2)
/LED Drivers/CS3_A: D117.2, D117.4, D117.6, D118.2, D118.4, D118.6, D119.2, D119.4, D119.6, D120.2, D120.4, D120.6, U5.18 (CS3)
/LED Drivers/CS4_A: D121.2, D121.4, D121.6, D122.2, D122.4, D122.6, D123.2, D123.4, D123.6, D124.2, D124.4, D124.6, U5.19 (CS4)
/LED Drivers/CS5_A: D125.2, D125.4, D125.6, D126.2, D126.4, D126.6, D127.2, D127.4, D127.6, D128.2, D128.4, D128.6, U5.21 (CS5)
/LED Drivers/CS6_A: D129.2, D129.4, D129.6, D130.2, D130.4, D130.6, D131.2, D131.4, D131.6, D132.2, D132.4, D132.6, U5.22 (CS6)
/LED Drivers/CS7_A: D133.2, D133.4, D133.6, D134.2, D134.4, D134.6, D135.2, D135.4, D135.6, D136.2, D136.4, D136.6, U5.23 (CS7)
/LED Drivers/CS8_A: D137.2, D137.4, D137.6, D138.2, D138.4, D138.6, D139.2, D139.4, D139.6, D140.2, D140.4, D140.6, U5.24 (CS8)
/LED Drivers/CS9_A: D141.2, D141.4, D141.6, D142.2, D142.4, D142.6, D143.2, D143.4, D143.6, D144.2, D144.4, D144.6, U5.25 (CS9)
/LED Drivers/CS10_A: D145.2, D145.4, D145.6, D146.2, D146.4, D146.6, D147.2, D147.4, D147.6, D148.2, D148.4, D148.6, U5.26 (CS10)
/LED Drivers/CS11_A: D149.2, D149.4, D149.6, D150.2, D150.4, D150.6, D151.2, D151.4, D151.6, D152.2, D152.4, D152.6, U5.27 (CS11)
/LED Drivers/CS12_A: D153.2, D153.4, D153.6, D154.2, D154.4, D154.6, D155.2, D155.4, D155.6, D156.2, D156.4, D156.6, U5.28 (CS12)
/LED Drivers/CS13_A: D157.2, D157.4, D157.6, D158.2, D158.4, D158.6, D159.2, D159.4, D159.6, D160.2, D160.4, D160.6, U5.30 (CS13)
/LED Drivers/CS14_A: D161.2, D161.4, D161.6, D162.2, D162.4, D162.6, D163.2, D163.4, D163.6, D164.2, D164.4, D164.6, U5.31 (CS14)
/LED Drivers/CS15_A: D165.2, D165.4, D165.6, D166.2, D166.4, D166.6, D167.2, D167.4, D167.6, D168.2, D168.4, D168.6, U5.32 (CS15)
/LED Drivers/CS16_A: D169.2, D169.4, D169.6, D170.2, D170.4, D170.6, D171.2, D171.4, D171.6, D172.2, D172.4, D172.6, U5.33 (CS16)
/LED Drivers/SW1_A: D112.1, D116.1, D120.1, D124.1, D128.1, D132.1, D136.1, D140.1, D144.1, D148.1, D152.1, D156.1, D160.1, D164.1, D168.1, D172.1, U5.2 (SW1)
/LED Drivers/SW2_A: D112.3, D116.3, D120.3, D124.3, D128.3, D132.3, D136.3, D140.3, D144.3, D148.3, D152.3, D156.3, D160.3, D164.3, D168.3, D172.3, U5.3 (SW2)
/LED Drivers/SW3_A: D112.5, D116.5, D120.5, D124.5, D128.5, D132.5, D136.5, D140.5, D144.5, D148.5, D152.5, D156.5, D160.5, D164.5, D168.5, D172.5, U5.4 (SW3)
/LED Drivers/SW4_A: D111.1, D115.1, D119.1, D123.1, D127.1, D131.1, D135.1, D139.1, D143.1, D147.1, D151.1, D155.1, D159.1, D163.1, D167.1, D171.1, U5.6 (SW4)
/LED Drivers/SW5_A: D111.3, D115.3, D119.3, D123.3, D127.3, D131.3, D135.3, D139.3, D143.3, D147.3, D151.3, D155.3, D159.3, D163.3, D167.3, D171.3, U5.7 (SW5)
/LED Drivers/SW6_A: D111.5, D115.5, D119.5, D123.5, D127.5, D131.5, D135.5, D139.5, D143.5, D147.5, D151.5, D155.5, D159.5, D163.5, D167.5, D171.5, U5.8 (SW6)
/LED Drivers/SW7_A: D110.1, D114.1, D118.1, D122.1, D126.1, D130.1, D134.1, D138.1, D142.1, D146.1, D150.1, D154.1, D158.1, D162.1, D166.1, D170.1, U5.9 (SW7)
/LED Drivers/SW8_A: D110.3, D114.3, D118.3, D122.3, D126.3, D130.3, D134.3, D138.3, D142.3, D146.3, D150.3, D154.3, D158.3, D162.3, D166.3, D170.3, U5.10 (SW8)
/LED Drivers/SW9_A: D110.5, D114.5, D118.5, D122.5, D126.5, D130.5, D134.5, D138.5, D142.5, D146.5, D150.5, D154.5, D158.5, D162.5, D166.5, D170.5, U5.11 (SW9)
/LED Drivers/SW10_A: D109.1, D113.1, D117.1, D121.1, D125.1, D129.1, D133.1, D137.1, D141.1, D145.1, D149.1, D153.1, D157.1, D161.1, D165.1, D169.1, U5.13 (SW10)
/LED Drivers/SW11_A: D109.3, D113.3, D117.3, D121.3, D125.3, D129.3, D133.3, D137.3, D141.3, D145.3, D149.3, D153.3, D157.3, D161.3, D165.3, D169.3, U5.14 (SW11)
/LED Drivers/SW12_A: D109.5, D113.5, D117.5, D121.5, D125.5, D129.5, D133.5, D137.5, D141.5, D145.5, D149.5, D153.5, D157.5, D161.5, D165.5, D169.5, U5.15 (SW12)
/LED Drivers/SYNC_OUT: U5.40 (SYNC); also elsewhere on the board
GND: C11.2, C12.2, C13.2, C14.2, C15.2, C16.2, C17.2, C26.2, R15.1, R17.2, U5.5 (PGND), U5.12 (PGND), U5.34 (AGND), U5.43 (ADDR1), U5.44 (ADDR2), U5.48 (GND), U5.49 (GND); also elsewhere on the board
unnamed: R15.2, U5.47 (IICRST)
unnamed: R16.1, U5.46 (~SDB)
unnamed: R17.1, U5.35 (RSET)
VCC: C11.1, C12.1, C13.1, C14.1, C15.1, C16.1, C17.1, U5.20 (PVCC), U5.29 (PVCC), U5.37 (AVCC), U5.38 (DVCC); also elsewhere on the board

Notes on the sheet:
LED_DRIVER_A PWR_FILTER
LED_DRIVER_A P29
LED_DRIVER_A P20
LED_DRIVER_A P37/38
LED Driver A - Addr 0x50
LED Driver A - Power Filtering

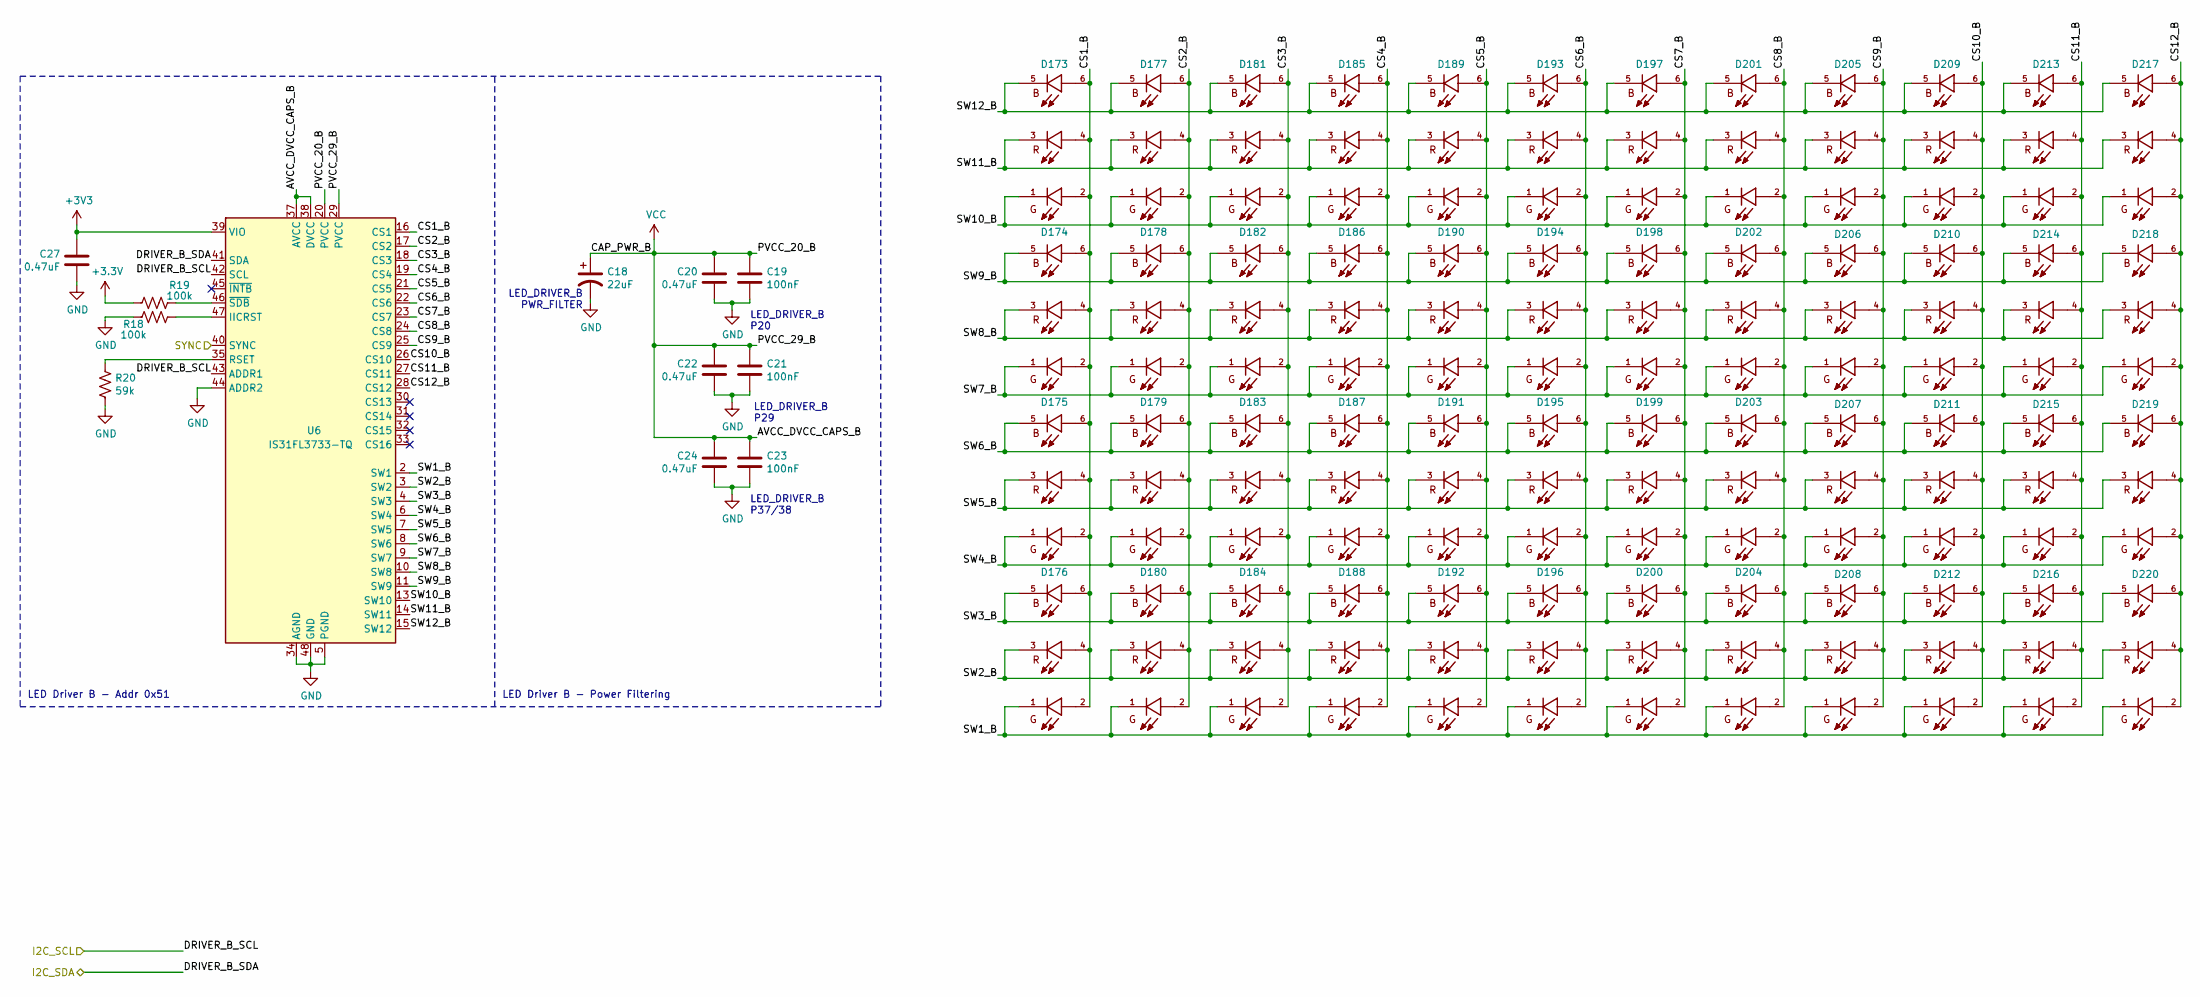
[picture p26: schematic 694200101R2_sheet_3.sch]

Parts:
C18: 22uF; CP_EIA-3528-21_Kemet-B
C19, C21, C23: 100nF; C_0603_1608Metric
C20, C22, C24, C27: 0.47uF; C_0603_1608Metric
D173, D174, D175, D176, D177, D178, D179, D180, D181, D182, D183, D184, D185, D186, D187, D188, D189, D190, D191, D192, D193, D194, D195, D196, D197, D198, D199, D200, D201, D202, D203, D204, D205, D206, D207, D208, D209, D210, D211, D212, D213, D214, D215, D216, D217, D218, D219, D220: 19-337C_RSBHGHC-A88_4T; 4T; PARTREV 2
R18, R19: 100k; R_0603_1608Metric
R20: 59k; R_2512_6332Metric
U6: IS31FL3733-TQ; TQFP-48-1EP_7x7mm_P0.5mm_EP5x5mm_ThermalVias

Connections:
/I2C_SCL: U6.42 (SCL), U6.43 (ADDR1); also elsewhere on the board
/I2C_SDA: U6.41 (SDA); also elsewhere on the board
/LED Drivers/LED Driver B/CS1_B: D173.2, D173.4, D173.6, D174.2, D174.4, D174.6, D175.2, D175.4, D175.6, D176.2, D176.4, D176.6, U6.16 (CS1)
/LED Drivers/LED Driver B/CS2_B: D177.2, D177.4, D177.6, D178.2, D178.4, D178.6, D179.2, D179.4, D179.6, D180.2, D180.4, D180.6, U6.17 (CS2)
/LED Drivers/LED Driver B/CS3_B: D181.2, D181.4, D181.6, D182.2, D182.4, D182.6, D183.2, D183.4, D183.6, D184.2, D184.4, D184.6, U6.18 (CS3)
/LED Drivers/LED Driver B/CS4_B: D185.2, D185.4, D185.6, D186.2, D186.4, D186.6, D187.2, D187.4, D187.6, D188.2, D188.4, D188.6, U6.19 (CS4)
/LED Drivers/LED Driver B/CS5_B: D189.2, D189.4, D189.6, D190.2, D190.4, D190.6, D191.2, D191.4, D191.6, D192.2, D192.4, D192.6, U6.21 (CS5)
/LED Drivers/LED Driver B/CS6_B: D193.2, D193.4, D193.6, D194.2, D194.4, D194.6, D195.2, D195.4, D195.6, D196.2, D196.4, D196.6, U6.22 (CS6)
/LED Drivers/LED Driver B/CS7_B: D197.2, D197.4, D197.6, D198.2, D198.4, D198.6, D199.2, D199.4, D199.6, D200.2, D200.4, D200.6, U6.23 (CS7)
/LED Drivers/LED Driver B/CS8_B: D201.2, D201.4, D201.6, D202.2, D202.4, D202.6, D203.2, D203.4, D203.6, D204.2, D204.4, D204.6, U6.24 (CS8)
/LED Drivers/LED Driver B/CS9_B: D205.2, D205.4, D205.6, D206.2, D206.4, D206.6, D207.2, D207.4, D207.6, D208.2, D208.4, D208.6, U6.25 (CS9)
/LED Drivers/LED Driver B/CS10_B: D209.2, D209.4, D209.6, D210.2, D210.4, D210.6, D211.2, D211.4, D211.6, D212.2, D212.4, D212.6, U6.26 (CS10)
/LED Drivers/LED Driver B/CS11_B: D213.2, D213.4, D213.6, D214.2, D214.4, D214.6, D215.2, D215.4, D215.6, D216.2, D216.4, D216.6, U6.27 (CS11)
/LED Drivers/LED Driver B/CS12_B: D217.2, D217.4, D217.6, D218.2, D218.4, D218.6, D219.2, D219.4, D219.6, D220.2, D220.4, D220.6, U6.28 (CS12)
/LED Drivers/LED Driver B/SW1_B: D176.1, D180.1, D184.1, D188.1, D192.1, D196.1, D200.1, D204.1, D208.1, D212.1, D216.1, D220.1, U6.2 (SW1)
/LED Drivers/LED Driver B/SW2_B: D176.3, D180.3, D184.3, D188.3, D192.3, D196.3, D200.3, D204.3, D208.3, D212.3, D216.3, D220.3, U6.3 (SW2)
/LED Drivers/LED Driver B/SW3_B: D176.5, D180.5, D184.5, D188.5, D192.5, D196.5, D200.5, D204.5, D208.5, D212.5, D216.5, D220.5, U6.4 (SW3)
/LED Drivers/LED Driver B/SW4_B: D175.1, D179.1, D183.1, D187.1, D191.1, D195.1, D199.1, D203.1, D207.1, D211.1, D215.1, D219.1, U6.6 (SW4)
/LED Drivers/LED Driver B/SW5_B: D175.3, D179.3, D183.3, D187.3, D191.3, D195.3, D199.3, D203.3, D207.3, D211.3, D215.3, D219.3, U6.7 (SW5)
/LED Drivers/LED Driver B/SW6_B: D175.5, D179.5, D183.5, D187.5, D191.5, D195.5, D199.5, D203.5, D207.5, D211.5, D215.5, D219.5, U6.8 (SW6)
/LED Drivers/LED Driver B/SW7_B: D174.1, D178.1, D182.1, D186.1, D190.1, D194.1, D198.1, D202.1, D206.1, D210.1, D214.1, D218.1, U6.9 (SW7)
/LED Drivers/LED Driver B/SW8_B: D174.3, D178.3, D182.3, D186.3, D190.3, D194.3, D198.3, D202.3, D206.3, D210.3, D214.3, D218.3, U6.10 (SW8)
/LED Drivers/LED Driver B/SW9_B: D174.5, D178.5, D182.5, D186.5, D190.5, D194.5, D198.5, D202.5, D206.5, D210.5, D214.5, D218.5, U6.11 (SW9)
/LED Drivers/LED Driver B/SW10_B: D173.1, D177.1, D181.1, D185.1, D189.1, D193.1, D197.1, D201.1, D205.1, D209.1, D213.1, D217.1, U6.13 (SW10)
/LED Drivers/LED Driver B/SW11_B: D173.3, D177.3, D181.3, D185.3, D189.3, D193.3, D197.3, D201.3, D205.3, D209.3, D213.3, D217.3, U6.14 (SW11)
/LED Drivers/LED Driver B/SW12_B: D173.5, D177.5, D181.5, D185.5, D189.5, D193.5, D197.5, D201.5, D205.5, D209.5, D213.5, D217.5, U6.15 (SW12)
/LED Drivers/SYNC_OUT: U6.40 (SYNC); also elsewhere on the board
GND: C18.2, C19.2, C20.2, C21.2, C22.2, C23.2, C24.2, C27.2, R18.1, R20.2, U6.5 (PGND), U6.12 (PGND), U6.34 (AGND), U6.44 (ADDR2), U6.48 (GND), U6.49 (GND); also elsewhere on the board
unnamed: R18.2, U6.47 (IICRST)
unnamed: R19.1, U6.46 (~SDB)
unnamed: R20.1, U6.35 (RSET)
VCC: C18.1, C19.1, C20.1, C21.1, C22.1, C23.1, C24.1, U6.20 (PVCC), U6.29 (PVCC), U6.37 (AVCC), U6.38 (DVCC); also elsewhere on the board

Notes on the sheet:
LED_DRIVER_B P29
LED_DRIVER_B P20
LED Driver B - Addr 0x51
LED Driver B - Power Filtering
LED_DRIVER_B PWR_FILTER
LED_DRIVER_B P37/38

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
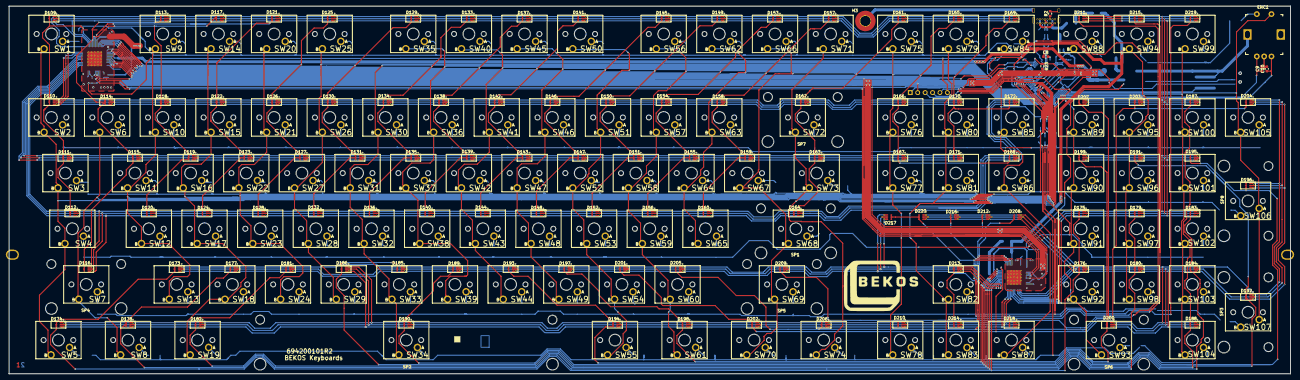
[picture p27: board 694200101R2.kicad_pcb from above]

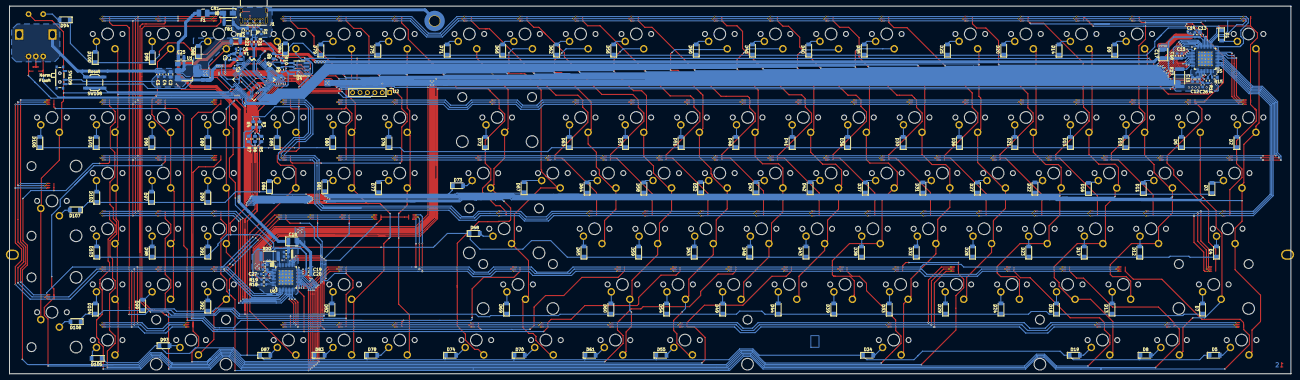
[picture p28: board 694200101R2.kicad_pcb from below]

Board: 2 copper layers, 438.6 x 125.8 mm, 400 parts (164 on the bottom side), 227 nets.

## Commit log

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2020-12-27 Added Inital Schematic Layout
    Added STM32 MCU
    Added USB C to USB 2.0
    Added LVO for MCU
    Added DFU reset for MCU
    [694200101.sch, Global_Connector_Technology_-_USB4085-GF-A.step, ON_Semiconductor_-_LL4148.step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]
2020-12-28 Updated Schemeatic for I2C
    Added I2C Bus
    Added EEPROM
    Added LED Drivers
    Added LED Driver A LED Array
    [6942000101R1_sheet_2.sch, 694200101.sch, Bourns_-_PEC11R-4220F-S0024.step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]
2020-12-30 Added B LED Driver and Initial plate deisgn
    Added Second LED Array
    Added DXF from ai03 and cusomized one for the volume/mute knob cut out
    [6942000101R1_sheet_2.sch, 694200101.sch, 694200101R1_sheet_2.sch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]
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2020-12-30 Added 3D Models
    Added 3D Models for all components
    Added Keyboard DXF for reference
    [6942000101R1_sheet_2.sch, 694200101.kicad_pcb, 694200101.sch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]
2020-12-30 fixed file names, added additional source
    [694200101R1_sheet_2.sch, 694200101R1_sheet_3.sch, 694210101R1.kicad_pcb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]
2020-12-30 Added MX Switch 3d Model
    [asm_mx_asm_PCB.stp, asm_mx_asm_PLATE.stp]
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2020-12-30 Added Missing Col_8
    [694200101.sch]
2020-12-30 Added Missing Wires
    [694200101.sch]
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2020-12-30 Flipped 3D model of MX Switch
2020-12-30 Added MillMax Sockets to MX Swtiches
    [mill-max-0305-2-15-80-47-XX-10-0.step]
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2020-12-30 Updated PCB To use new models
    [694200101.kicad_pcb]
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2020-12-30 some of row 5
    [694200101.kicad_pcb]
2020-12-30 Updated PCB 3D models
    [694200101.kicad_pcb]
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2020-12-30 diodes for columns 0-3 laidout
    [694200101.kicad_pcb]
2020-12-31 Updated Footprints and Added Stabs
    Updated footprints to be less messy and clearer on the silkscreen
    Added MX Stabs in proximity to where they'll actually end up going
    [694200101.kicad_pcb]
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2020-12-31 Fixed Missing Footprint Lib
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2020-12-31 Added USB ESD Protection IC
    [USBLC6-2P6.step]
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2020-12-31 Fixed Encoder and Stabs
    [694200101.kicad_pcb]
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2020-12-31 Fixed Incorrect Placemnt of MX Stabs
    [694200101.kicad_pcb]
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2020-12-31 Updated Schematic to use Crystal
    [694200101.sch, AVX_-_06035A100JAT2A.step]
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2020-12-31 Added New Crystal to Schematic
    [694200101.sch]
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2020-12-31 LED footprint added pth
    [694200101.kicad_pcb]
2020-12-31 Added Debug Header for Nucleo
    Added debug headers for ST-V2-1 Nucleo board for advanced debugging
    [694200101.sch]
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2020-12-31 Added New Debug header to PCB
    [694200101.kicad_pcb]
2020-12-31 straightened diodes row 1
    [694200101.kicad_pcb]
2020-12-31 Added Stabs as Components
    [694200101.kicad_pcb, 694200101.sch]
2020-12-31 allign more diodes, bottom half
    [694200101.kicad_pcb, 694200101.sch]
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2020-12-31 updaed silkscreen on led driver
    [694200101.kicad_pcb]
2020-12-31 Fixed Missing I2C Net
    [694200101.kicad_pcb, 694200101.sch, 694200101R1_sheet_2.sch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]
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2021-01-01 Added Better Encoder Model
    Added Better Encoder Model
    Fixed RGB LED mouting type in footprint
    [PEC11L-4xxxF-Sxxxx.stp]
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2021-01-01 layout led driver 1
    [694200101.kicad_pcb, 694200101R1_sheet_2.sch]
2021-01-01 Update 694200101.kicad_pcb
    begun LED traces
    [694200101.kicad_pcb]
2021-01-01 routed LED fir driver 1
    [694200101.kicad_pcb]
2021-01-01 LED traces driver 2 row 1-2
    [694200101.kicad_pcb]
2021-01-01 Update 694200101.kicad_pcb
    update led driver location
    [694200101.kicad_pcb]
2021-01-04 Updated USB C protection Circuit
    Added PTC fuse and choke for surge suppression.
    Added ferrite bead to reduce coupling
    [694200101.kicad_pcb, 694200101.sch, FBMJ3216HM600-T.step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]
2021-01-05 Updated PCB with new components
    [694200101.sch]
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2021-01-06 Added Different Ferrite Bead
    [694200101.sch]
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2021-01-07 trying to fix fb1
    [694200101.kicad_pcb, 694200101.sch]
2021-01-07 Fixed Ferrite Bead Footprint
    [694200101.sch]
2021-01-07 Fixed missing pin numbers on Ferrite Bead
2021-01-07 Fixed Missing Pins in Schmatic
    [694200101.sch]
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2021-01-07 Fixed 3D model of MX Switch
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2021-01-07 row 6 row traces
    [694200101.kicad_pcb, 694200101.sch]
2021-01-07 Added Mounting Holes and alignment slots
    [694200101.kicad_pcb, 694200101.sch]
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2021-01-07 side slots and switch row 2
    [694200101.kicad_pcb]
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2021-01-09 Updated Schmeatic to use different Diode
    [694200101.kicad_pcb, 694200101.sch, 694200101R1_sheet_2.sch]
2021-01-09 Deleted unneeded footprints on PCB
    [694200101.kicad_pcb]
2021-01-09 Revert "Deleted unneeded footprints on PCB"
    This reverts commit 762b3a794928e0b052099208c817aea117a18dbd.
    [694200101.kicad_pcb]
2021-01-09 Revert "Updated Schmeatic to use different Diode"
    This reverts commit 2ef9e9146f74f64269d04d4aff430c07a136243a.
    [694200101.kicad_pcb, 694200101.sch, 694200101R1_sheet_2.sch]
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2021-01-09 updated switch footprint
    need to fix silkscrre interfearence on switch footprint
    [694200101.kicad_pcb]
2021-01-13 cpoied second led driver
    [694200101.kicad_pcb]
2021-01-13 led driver a layout pt1
    [694200101.kicad_pcb]
2021-01-13 Fixed incorrect pull-down resistors
    [694200101R1_sheet_2.sch]
2021-01-14 connected sw side of u5
    [694200101.kicad_pcb]
2021-01-14 almost done with LER driver u5
    [694200101.kicad_pcb]
2021-01-15 Updated LED Driver Footprint to have termal vias
    [694200101.kicad_pcb, 694200101R1_sheet_2.sch]
2021-01-15 Picked the actual correct footprint for the LED drivers
    [694200101.kicad_pcb, 694200101R1_sheet_2.sch]
2021-01-21 led csa in progress
    ledm csa in progress
    [694200101.kicad_pcb]
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2021-01-21 started led driver 2
    [694200101.kicad_pcb]
2021-01-21 Updated LED Driver Footprint
    Updated LED driver footprint to fix back mask being larger than needed and moved the vias closer
    [694200101.kicad_pcb, 694200101R1_sheet_2.sch]
2021-01-21 really complete driver a
    [694200101.kicad_pcb]
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2021-01-28 moar led driver b
    [694200101.kicad_pcb]
2021-01-28 stab clearance
    [694200101.kicad_pcb]
2021-01-28 getting shupid csb out of lala land
    [694200101.kicad_pcb]
2021-02-04 added led switch pair list
    [LED_switch_pairs.xlsx]
2021-02-04 mostly done driver b
    [694200101.kicad_pcb, LED_switch_pairs.xlsx]
2021-02-11 led driver b power
    [694200101.kicad_pcb]
2021-02-11 named restet net properly
    [694200101.kicad_pcb, 694200101.sch]
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2021-02-18 routing power and other mcu stuff
    [694200101.kicad_pcb]
2021-02-25 FUK U MCU DUN
    [694200101.kicad_pcb]
2021-02-25 COJMPLETE NQA LED A
    [694200101.kicad_pcb]
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2021-02-27 Updated PCB Footprints to add 3D models
    Added missing 3D models for parts to help with case design later down the line.
    [694200101.kicad_pcb, 694200101.sch, KX7 SMD Quartz Crystal Resonator 3.2x2.5mm.step]
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2021-03-11 fixed LED
    [694200101.kicad_pcb]
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2021-04-08 Added 0 Ohm resistors for USB Data lines
    [694200101.csv, 694200101.kicad_pcb, 694200101.sch]
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2021-04-10 fiked data short
    [694200101.kicad_pcb]
2021-04-10 Revert "Added Logo to PCB"
    This reverts commit c429ff769e35cd6cf0a76a8cfb685bedc6b738e9.
    [694200101-seeed.csv, 694200101.kicad_pcb, 694200101.sch]
2021-04-10 fixedf gnd via
    [694200101.kicad_pcb]
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2021-04-15 fixed power to led drivers
    [694200101.kicad_pcb, 694200101.sch, 694200101R1_sheet_2.sch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]
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2021-04-20 Fixed USB C hole
    [694200101-seeed.csv, 694200101.kicad_pcb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]
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2021-05-29 Updated USB C Connector
    Connector didn't have proper soldermask so we need to use a proper footprint that is compatible
    [694200101-seeed.csv, 694200101.kicad_pcb, 694200101.sch]
2021-05-29 fixed usb
    [694200101.kicad_pcb]
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2021-05-31 dill files fixed
    [694200101-NPTH-drl_map.gbr, 694200101-NPTH.drl, 694200101-PTH-drl_map.gbr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]
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2021-10-27 Prettied up schematic
    Updated Schematic to be more readable and not as crazily wired
    [694200101R2.kicad_pcb, 694200101R2.sch, 694200101R2_sheet_2.sch]
2021-11-02 Update 694200101R2.kicad_pcb
    Fixed positioning of USB C connector
    [694200101R2.kicad_pcb]
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2022-04-28 fixed protection schematic
    [694200101R2.sch]
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2022-05-19 fixing more led drivcer
    [694200101R2.kicad_pcb]
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2022-05-27 Updated Footprints and Fixed Schematic Warnings
    [694200101R2.sch, 694200101R2_sheet_2.sch]
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2022-05-29 Updated Schematic to use KiCad LED Driver Symbols
    [694200101R2.sch, 694200101R2_sheet_2.sch, 694200101R2_sheet_3.sch]
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2022-06-01 Fix Ferrite Bead Placement
    [694200101R2.sch]
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2022-06-02 Added extra ferrite bead
    You can never have too much power cleanup
    [694200101R2.sch]
2022-06-02 Fixed merge issues in schematic
    [694200101R2.sch]
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2022-06-02 Fixed Ratsnest errors from prettifying schematic
    [694200101R2.kicad_pcb, 694200101R2.sch, 694200101R2_sheet_2.sch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]
2022-06-02 Fixed Symbol for LDO
    [694200101R2.kicad_pcb, 694200101R2.sch]
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2022-06-03 Updated Footprints to have CAD Models
    Need footprints on board to allow for case modifications
    [694200101R2.kicad_pcb, 694200101R2.sch, 694200101R2_sheet_2.sch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]
2022-06-04 Hooked up Reset and Boot Set switch
    [694200101R2.kicad_pcb]
2022-06-05 Change BOOT0 Switch to one that's lower profile
    [694200101R2.kicad_pcb, 694200101R2.sch]
2022-06-08 Update fuse 3D Model and attach some missing nets
    [694200101R2.kicad_pcb, 694200101R2.sch]
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2022-06-09 fix reset and programming switches
    [694200101R2.kicad_pcb]
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2022-06-09 Initial Silkscreen rework
    [694200101R2.kicad_pcb]
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2022-06-30 Fix USB pair routing from connector
    [694200101R2.kicad_pcb]
2022-07-06 Fix Silkscreen for USB C and C23
    [694200101R2.kicad_pcb]
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

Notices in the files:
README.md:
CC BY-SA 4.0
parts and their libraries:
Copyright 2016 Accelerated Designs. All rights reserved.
